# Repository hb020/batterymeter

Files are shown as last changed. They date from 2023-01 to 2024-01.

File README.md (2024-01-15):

# Handheld Battery Meter on Attiny series 2 <!-- omit in toc -->

This repository is about a "pen size" (handheld) tool for quick measurement of various types of battery resistances/impedances.

This tool uses 2 different methods for measuring impedance values:

- "standard" AC 1 kHz impedance, as used by many.
- Direct Current Impedance Spectroscopy, extracting the bulk (solution) resistance and the SEI (Solid Electrolyte Interphase) resistance, allowing better insight in both battery ageing and battery safety. Normally this would require a lengthy procedure via EIS (Electrochemical Impedance Spectroscopy) and model fitting. This tool allows to do it fast and easy.

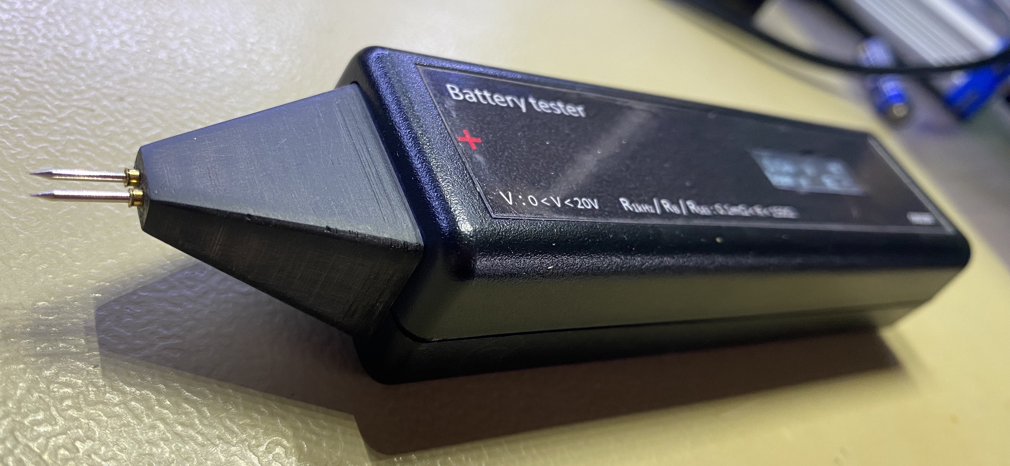
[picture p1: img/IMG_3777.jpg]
front image

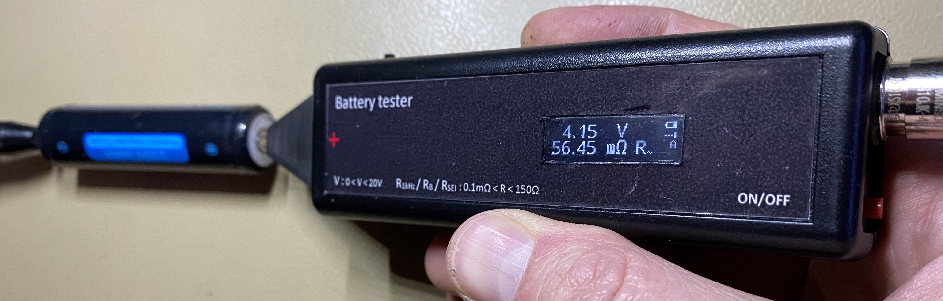
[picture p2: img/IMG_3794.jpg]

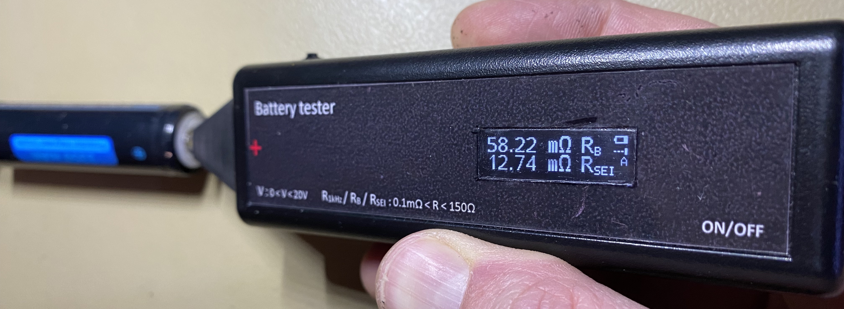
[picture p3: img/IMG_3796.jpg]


## Contents <!-- omit in toc -->

This document handles the reasoning behind the creation of this tool, the methods used, the software and the hardware.

- [Design restrictions](#design-restrictions)
- [Norms and introduction to measurement techniques used](#norms-and-introduction-to-measurement-techniques-used)
- [Battery Equivalent Circuit Model, Spectrum, and the EIS method](#battery-equivalent-circuit-model-spectrum-and-the-eis-method)
  - [Battery Equivalent Circuit Model](#battery-equivalent-circuit-model)
  - [EIS](#eis)
  - [Tools](#tools)
  - [CN0510](#cn0510)
  - [Model fitting](#model-fitting)
  - [Further information](#further-information)
- [Time Domain / DCIS method](#time-domain--dcis-method)
  - [Non-linear behaviour](#non-linear-behaviour)
  - [Pulse timing](#pulse-timing)
  - [Adaptation to other battery layouts or chemistries](#adaptation-to-other-battery-layouts-or-chemistries)
  - [Ratiometric approach](#ratiometric-approach)
  - [Offset cancelling](#offset-cancelling)
  - [Power line Frequency compensation](#power-line-frequency-compensation)
- [Internal Impedance (AC) measurement](#internal-impedance-ac-measurement)
  - [Current levels and test duration](#current-levels-and-test-duration)
  - [Implementation of the sine wave generation](#implementation-of-the-sine-wave-generation)
  - [AC Analysis method](#ac-analysis-method)
  - [ADC sampling considerations](#adc-sampling-considerations)
  - [Ratiometric approach, Offset cancelling, Power line Frequency compensation](#ratiometric-approach-offset-cancelling-power-line-frequency-compensation)
- [Internal Resistance (DC/IR) measurement](#internal-resistance-dcir-measurement)
- [CPU and Software environment](#cpu-and-software-environment)
- [Construction, Connectors, other hardware](#construction-connectors-other-hardware)
  - [Charging](#charging)
- [Buttons](#buttons)
- [Calibration](#calibration)
- [Remote control, SCPI](#remote-control-scpi)
- [Specifications](#specifications)
  - [Voltage](#voltage)
  - [Resistance](#resistance)
- [Repository contents](#repository-contents)
- [Imperfections, TODO's](#imperfections-todos)

---

## Design restrictions

This tool was designed with the following design restrictions:

- handheld, therefore:
  - small
  - limited controls, ideally by 1 finger while measuring
  - "large enough" screen
  - rechargeable
  - no need to cover a large temperature range
- fast measurement
- easy to use
- for use on regular small batteries. No large capacity car batteries or large UPS batteries, and nothing requiring extreme precision. Therefore:
  - at least 0 to 20 Ω, with, and at least 1 mΩ resolution at the lowest range.
  - at least 1V to 16V, and at least 10mV resolution.
  - at least 3 significant digits.
- precision is more important than accuracy. However, 1% accuracy should be attainable on resistance values. Voltage accuracy is of lower priority, as my DMMs can be used for that, and the voltage is less significant in most cases. Therefore:
  - aim for low noise
  - the accuracy of the measuring techniques should depend on as few as possible variables.
  - calibration must be possible.
- USB charging and USB interface
- hand assembly and hand soldering. For me, that means:
  - no BGA or QFN, as I don't have a reflow oven and am too much of a cheapskate to order stencils for the 1 or 2 PCBs I'll make.
  - 0805 components and VSSOP/MSOP 0.5mm pitch are the low limits
  - as a side effect, I can now freely use both sides of the PCB because I don't have to care about warping or components falling off the other side while soldering with hot air.
- using components that I can find in this period of component shortage. This means that sometimes there might be cheaper or better components, they were just not available when I selected them.
- using an Attiny series 2 CPU, because I wanted to try that out and it looked just capable enough. I really would have liked to use the RP2040, but it is not hand solderable enough. Maybe later.
- capable of using the probes that come with the YR1035+, as I also have that tool, and like the connector/probe ease of use/availability. It will also allow me to have easier comparisons.

## Norms and introduction to measurement techniques used

Battery impedance is a complicated subject. A battery does not have <u>one</u> impedance, and even if you get a number, it can mean many things. Also, the battery impedance depends on a lot of different things, like state of charge (SoC), state of health (SoH), temperature, and of course the measurement method. Therefore, various norms exist for measuring the various resistances and impedances of the different battery types. Some of them are:

- IEC 61951-1: NiCd
- IEC 61951-2: NiMH
- IEC 62660-1/2: Li-Ion
- IEC 61960-4: Lithium coin cells

Outside of these norms, various other test methods have arisen lately. Below is an explanation of the different methods I investigated.

---

## Battery Equivalent Circuit Model, Spectrum, and the EIS method

### Battery Equivalent Circuit Model

Various models of battery impedance exist, depending on the chemistry. For Li-Ion cells, the "Combined Randle and Warburg Circuit Model" is often cited as fairly complete, and, with some variations, also applicable to some other chemistries.

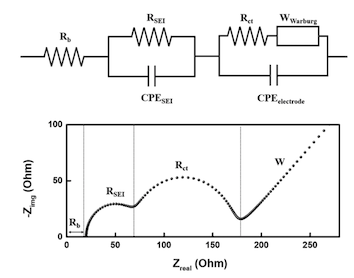
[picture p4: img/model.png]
Model and spectrum model and spectrum


*Equivalent circuit model of a Li-Ion battery half-cell system, and nyquist plot of a frequency sweep.*
([source](https://www.jecst.org/upload/pdf/jecst-2019-00528.pdf))

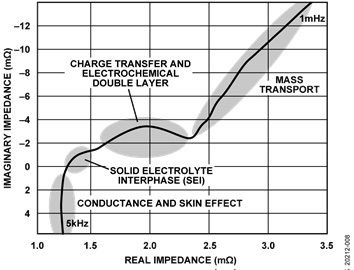
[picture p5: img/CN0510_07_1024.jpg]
Nyquist plot


*Nyquist plot, related to Li-Ion cell chemical processes.*
([source](https://www.analog.com/en/design-center/reference-designs/circuits-from-the-lab/CN0510.html))

### EIS

The EIS (Electrochemical Impedance Spectroscopy) method allows one to get a good view of the various components of the battery impedance. With this method an AC load of varying frequency is imposed on the battery, and the voltage swing over the battery is measured. The frequency sweep can go from the millihertz into the megahertz range, and can be used to generate a Nyquist plot like shown above.

Through model fitting, the values of the individual components in the model can than be determined.

For Li-Ion, the values of these components can be used as indicators.

- R<sub>b</sub> (aka R<sub>s</sub> or R<sub>Ω</sub> in other literature) = Bulk (or Solution) resistance. Increases when the battery ages.
- R<sub>SEI</sub> = Solid Electrolyte Interphase resistance. Is an indication of battery safety: it increases for example when the battery has been overcharged.
- R<sub>ct</sub> = Charge Transfer resistance. Increases when the battery is discharged, and when the temperature is lower. At a stable temperature and SoC, it is also a very good indication of battery health.

As an example, experimental results on Li-Ion batteries show that when the battery capacity drops from 3100 mAh to 2600 mAh due to ageing, the value of R<sub>b</sub> rises from 44 mΩ to 51 mΩ, the value of R<sub>SEI</sub> remains between 6 mΩ and 7 mΩ, and the value of R<sub>ct</sub> rises from 6 mΩ to 20 mΩ.

In spite of the insights EIS can give, it has a couple of drawbacks:

- The values are strongly dependent on the battery chemistry and construction details.
- Interpretation can be complicated.
- The data is too complex to show on a small screen.
- A full EIS test generally takes significant time

As a result, this method is very interesting, but unsuited for implementation in a handheld tool.

Fast measurement of full impedance spectra is possible via the use of multi-sine methods, or via time domain methods. More about this later on.

### Tools

Few "small lab" tools exist that support EIS. Examples are the [Biologic Potentiostat](https://www.biologic.net/product_category/potentiostats-galvanostats/), [Hioki IM3590 and BT4560](https://www.hioki.com/download/37483), or the [BK Precision BA8100](https://www.bkprecision.com/products/electrical-battery-testers/BA8100), all costing several thousands of Euros. But one can already get an idea about EIS via the CN0510 circuit, for a significantly lower budget:

### CN0510

An implementation example of a tool is [CN0510 from analog.com](https://www.analog.com/en/design-center/reference-designs/circuits-from-the-lab/CN0510.html). It allows EIS measurements on various types of batteries. Note however that the signal handling board (EVAL-AD5941BATZ), by default, is only usable in the frequency range of about 4Hz - 5Khz. Outside of that, the accuracy is degraded, and below 1Hz, the noise of the input circuitry gets quite noticeable (1/f noise). With the following minor modifications, 0.5Hz - 5kHz can be made possible though:

- add U4 (otherwise the first couple of seconds of measurements are totally off)
- change C5, C6, C36, C37, C38, C39 from 2.2uF to 10uF.
- change R18, R19, R2, R3, R4, R5 from 2Meg to 10Meg.

### Model fitting

For the impedance analysis and the model fitting, several software packages exist, like [ZView](https://www.scribner.com/software/) or [impedance.py](https://github.com/ECSHackWeek/impedance.py). See the [/EISMeasurements](/EISMeasurements) directory in this repository for some fitting tests with both of these tools.

### Further information

For more information on EIS and alternative methods, see for example <https://www.gamry.com/application-notes/EIS/basics-of-electrochemical-impedance-spectroscopy/> or <https://doi.org/10.1016/j.jpowsour.2020.228742>.

Note that EIS is used in a lot of fields, not only for batteries. However, research on batteries has gotten a significant boost lately with the widespread arrival of electric cars.

---

## Time Domain / DCIS method

As mentioned above, EIS frequency domain analysis is not only complicated, but also lengthy. Time domain analysis methods have come up lately that allow acceptable approximations to the results that can be obtained via EIS. One of the approaches is called DCIS (Direct Current Impedance Spectroscopy), which is described here: <https://www.mdpi.com/1996-1073/14/15/4396/htm>

The idea behind DCIS (and other time domain methods) is that when one exposes the battery to current pulses, the voltage relaxation times give away details of the different RC components in the battery model. Care must be taken to exclude non linear behaviour and to tune the current pulses in such a way that the correct components can be derived easily.

### Non-linear behaviour

One key phrase:

> In the battery model, when the polarization potential change |∆ϕ| caused by an external signal is less than 10 mV and the signal time is short enough, the effect of concentration polarization (Zd in battery model) can be ignored.

I therefore need to keep the test currents low, and the pulses short. Both requirements perfectly fit my tool's design requirements.

### Pulse timing

In regular Li-Ion batteries, the various components show at various frequencies:

- R<sub>b</sub>: > 1kHz
- R<sub>SEI</sub> (and CPE<sub>SEI</sub>): > 1Hz, < 1kHz
- R<sub>ct</sub> (and CPE<sub>electrode</sub> and W): < 1Hz

The approach is that for every individual component, 1 specific timed constant current pulse will be used. The width of the pulse is about 5 * RC time of the component. That gives:

- for R<sub>b</sub>: T<sub>1</sub> = 0.25ms
- for R<sub>SEI</sub>: T<sub>2</sub> = 10ms
- for R<sub>ct</sub>: T<sub>3</sub> = 400ms

The pulses are spaced out by a small relaxation time. The voltage drop over the battery is measured at the end of each current pulse, and the battery resistance at that point in time is calculated:

- for T<sub>1</sub>: V<sub>drop</sub> / I<sub>pulse</sub> = R<sub>b</sub>
- for T<sub>2</sub>: V<sub>drop</sub> / I<sub>pulse</sub> = R<sub>b</sub> + R<sub>SEI</sub>
- for T<sub>3</sub>: V<sub>drop</sub> / I<sub>pulse</sub> = R<sub>b</sub> + R<sub>SEI</sub> + R<sub>ct</sub>

Unfortunately, I will want to do multiple measurements to drown out noise and do power line frequency compensation. That makes T<sub>3</sub> unsuited for my tool, and I must limit myself to  R<sub>b</sub> and R<sub>SEI</sub>.

### Adaptation to other battery layouts or chemistries

The timings mentioned above are suitable for your average Li-Ion 18650 cell. If you want to use the DCIS method on other battery layouts or chemistries, you can adapt the timings via SCPI commands (see `CAL:T(1|2|PAUSE) {uint16}` below).

### Ratiometric approach

The current pulse is sent through the battery, that is placed in series with a known resistor.
The battery resistance is deducted from the relation between the voltage fluctuation over the known resistor and the voltage fluctuation over the battery. Hence, there is no need for a known current source, nor a known voltage reference.

With U<sub>batt</sub> as the voltage drop over the battery, U<sub>ref</sub> the voltage over the reference resistor, and R<sub>ref</sub> the reference resistor: R<sub>batt</sub> = R<sub>ref</sub> * (U<sub>batt</sub>/U<sub>ref</sub>).

Since U<sub>batt</sub> and U<sub>ref</sub> are so small, they are amplified by an AC coupled low noise instrumentation amplifier. The output signal is fed into the differential ADC of the processor. In order to avoid amplification differences and other signal path differences, multiplexing via a common measurement circuit is used. An input switch allows switching between the battery and the reference resistor.

The frequency cut-off point of the high-pass filter at the input of the instrumentation amplifier is well below the frequencies used in the measurements.

### Offset cancelling

The (potentially large) DC offset at the entry of the circuit is cancelled at the start of the measurements, by a low impedance short of the signal to VCC/2. The short is applied for as long is needed, and stopped when the processor sees a close to 0V differential signal on the ADC.

### Power line Frequency compensation

In order to reduce the noise and the influence of the power line frequency, multiple samples are taken, and the results are averaged. The timing of the samples is adapted to the configured power line frequency: an identical number of samples is taken for each opposing polarity of the power line signal.

The software allows setting of the power line frequency (50 or 60) via SCPI commands.

---

## Internal Impedance (AC) measurement

This is the industry standard AC 1kHz test. A small 1kHz current (ideally sine wave) is applied to the battery, and the AC voltage at the battery is measured. The impedance is then deducted from the current and the voltage.
This method is widespread, low power, and fast, so I can include it in my tool.

### Current levels and test duration

The maximum voltage swing allowed depends on the battery type, as above certain levels, the values would be skewed by other factors. For NiCd, that limit is about 20mV, and for Lithium chemistries, 10mV seems to be indicated. As a result, I do not set a test specific current, but adapt the test current to the selected range.

The "correct" duration of the test varies. EC 61951-1 for example states that the test duration must be 1 to 5 seconds, but that is not handy for fast manual use. A test duration of 100ms suffices normally.

### Implementation of the sine wave generation

The CPU I chose does not have a sine wave generator. It does have PWM, but making a sine wave with that was hard to do while running the ADC. As a result, I generate a 1kHz square wave on CPU, and do the transformation to a sine wave with an analog phase-shift circuit. That signal is then, after some amplification and level shifting, fed into a voltage controlled current sink.

### AC Analysis method

Instead of a full fledged FFT/DFT, Goertzel's Algorithm is used. It is essentially a mathematical bandpass filter that gives a magnitude (and phase) reading. It is especially suited as I generate the 1kHz tone myself and can sync the ADC sampling to that tone generation. As a result, it is very light on resources: I can do the calculations while sampling, and do not need large memory buffers.

About the configuration of Goertzel:

- nr_of_samples (N) should be as high as possible:
  - sample_rate/N is bin width.
  - more samples therefore gives more noise suppression
- Target frequencies must be integer multiples of sample_rate/N

Some of the inspirations:

- <https://www.embedded.com/the-goertzel-algorithm/>
- <https://fr.mathworks.com/matlabcentral/answers/?language=fr%2Cen&search_origin=ans_browse&term=goertzel>

### ADC sampling considerations

The CPU having limited RAM, I prefer to do the tone generation, ADC sampling and AC analysis all in sync, run-time. I do not sample and analyse later, as that would take too much RAM. It also gives me the possibility to make the sampling as long as I want, increasing noise suppression. It however requires an optimised ADC loop, so I go outside of megaTinyCore's analogRead() function.

As I have low noise pre-amps, I do not use the PGA: I set gain 0.

The trigger generator is TCA0, the most capable of the timers on the CPU, and I trigger the ADC sampling via the Event system (ADC_START_EVENT_TRIGGER_gc and USERADC0START). During sampling, I generate the 1kHz square wave in code, and do the Goertzel calculations.
Tests have shown that at a 10kHz trigger signal, I have about 20us CPU time left per sample. 12kHz would not be possible, unless I raise the ADC clock rate. Maybe also CCL could help, but I haven't looked.

Interrupts are only used for error conditions on the ADC. Other interrupt sources, like the time library, are disabled, as it would provoke jitter or overruns.

As this is time critical code, debugging support is available in code, via USEREVSYSEVOUTC for example.

I do not use tone(), as that is interrupt driven.

### Ratiometric approach, Offset cancelling, Power line Frequency compensation

A sine wave of 1 kHz is sent through the battery, that is placed in series with a known resistor.
The battery resistance is deducted from the relation between the AC voltage over the known resistor and the AC voltage over the battery. Hence, there is no need for a known current source, nor a known voltage reference.

For more details, see the chapter on "Ratiometric approach" in the description of the DCIS method.

Also here, DC offset cancelling and power line frequency compensation is used. See the related chapters in the description of the DCIS method.

---

## Internal Resistance (DC/IR) measurement

This method is frequently encountered, because it is very simple. It is in essence a DC measurement technique.

> The cell shall be discharged at a constant current of value I<sub>1</sub>. At the end of a discharge period of T<sub>1</sub> s, the voltage U<sub>1</sub> during discharge shall be measured and recorded. The discharge current shall then be immediately increased to a constant value of I<sub>2</sub>, and the corresponding voltage U<sub>2</sub> during discharge shall be measured and recorded again at the end of a discharge period of T<sub>2</sub> s.

Therefore: R<sub>dc</sub> = (U<sub>1</sub> - U<sub>2</sub>)/(I<sub>2</sub> - I<sub>1</sub>)

The currents I<sub>1</sub> and I<sub>2</sub>, and the times T<sub>1</sub> and T<sub>2</sub> depend on the type and capacity of the battery. Example: For NiCd, I<sub>1</sub> is normally between 0.2 and 1 times the C value in Amps, I<sub>2</sub> = 10 * I<sub>1</sub>, T<sub>1</sub> = 10, T<sub>2</sub> = 3. For Lead Acid batteries, the currents can become even larger.

Those large currents, and the accompanying dissipation, make it unsuited for integration in a small handheld tool. Also, because this is such a crude method, abstracting most of the battery model, I am not using this method.

---

## CPU and Software environment

- Arduino IDE (unfortunately. platformIO was not very mature at the time of creation: board support had just arrived.)
- megaTinyCore
- CPU: Attiny 3266-SU (SOIC300, non automotive, 32kB Flash, 3kB RAM, 256B EEPROM)
- Display (SSD1306) via Tiny4kOLED (not SSD1306_minimal, as that is less maintained)
- SparkFun_PCA9536_Arduino_Library
- a modified and local version of vrekrer's scpi_parser

Please note that the flash memory is close to the limit: it is 97% full.

## Construction, Connectors, other hardware

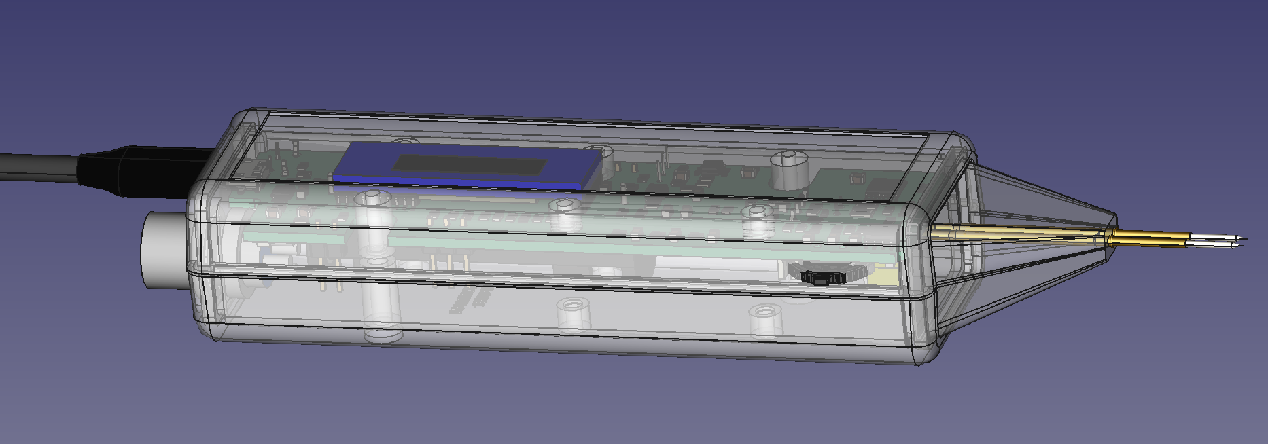
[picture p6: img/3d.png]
3d image

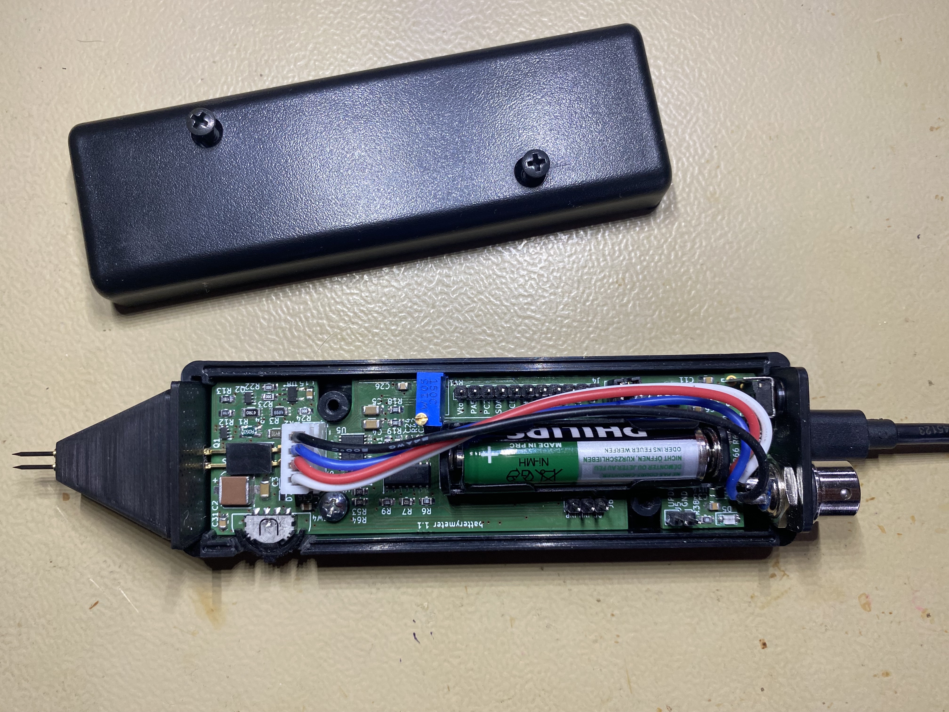
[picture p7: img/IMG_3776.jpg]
open image


The case chosen is a Hammond 1593DBK. That case comes with flat and curved front/back panels. Use the flat one for the back.

The nose cone is 3D printed, see the [nose cone STEP file](/freecad/noseCone.STEP). The holes for the pins may be too small, I had to drill them out.

The pogo pins in the nose cone are regular R100-1W sockets, with P100-B1 pogo pins. For images and dimensions, see the `pogo-*` files in the [/img](/img) folder.

The probe connector at the back is a "avionics" XS10 4P male connector, the same as on the YR1035+. This connector accepts regular YR1035+ compatible 4W probes, or in conjunction with the nose pogo pins, a custom made - probe (just half of the regular 4W probe). The nose pogo pins are directly connected to the + pins on the XS10 connector. As a result, one can also connect a 4W rig:

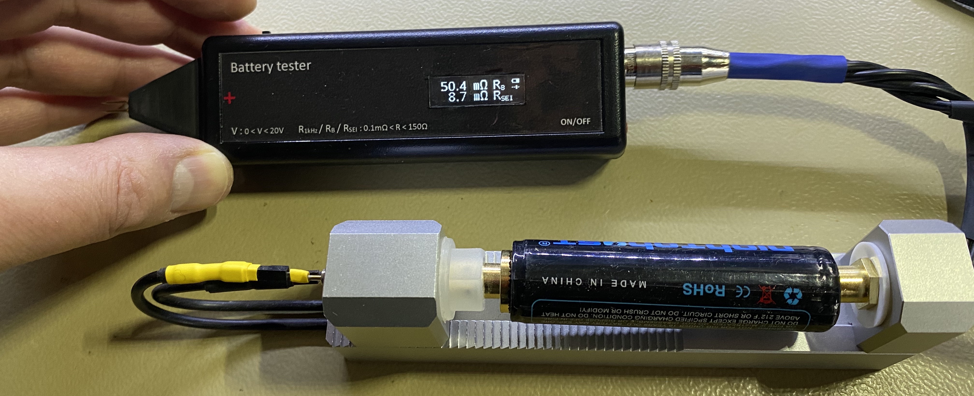
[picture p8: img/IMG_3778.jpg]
rig image


The serial connector/charge plug is a USB micro B. I should have chosen USB-C, but I still had a lot of USB micro B connectors.

The navigation switch is a SLLB510100 from Alps Alpine. You probably need some glue to fix it on the PCB, as the "fixing" tabs on the side are very/too small.

The reference resistors are all used in a 4W (kelvin) setup, either through the use of 4W resistors, or in a "poor man's" way, via the PCB layout:

kelvin connection.

All components on the board are specified in the kicad files. The choice of components is, as can be expected, influenced by the component shortage during 2021-2022.

The input circuitry is protected against reverse polarity and moderate overvoltage.

### Charging

If a rechargeable battery is used, the USB charges the battery via trickle charging at about 0.05C for your average 850mAh NiMh AAA battery. This charge current is so little that charging while ON is not possible. Therefore: Charge while OFF.

## Buttons

ON: short press button at the back.

OFF: long press button at the back, or via software control.

Switch between AC and DCIS measurement, or leave remote control: press the navigation switch.

Change range: via left/right of the navigation switch. The 'Auto' range is at both ends.

Note that due to the time-critical way the measurements are done, button presses are only detected between measurements, sometimes resulting in sluggish reactivity. See below under [Imperfections](#imperfections-todos).

## Calibration

The procedure for the calibration of the trim pot on the PCB is explained in the schematic.

The calibration of the current ranges is best done through measurement of the used resistors, and storage via the SCPI commands, or via code.

## Remote control, SCPI

By default, the meter prints out all measurement results on the USB serial output:

- __AC__: "AC: {R<sub>~</sub>}, {test voltage} V"
- __DCIS__: "DCIS: {R<sub>b</sub>}, {R<sub>SEI</sub>}, {test voltage} V"

The serial interface also supports a reduced set of SCPI commands. Any command (valid or not valid) on the serial interface will interrupt "local" measurements, and will allow remote control via the SCPI commands. To go back to "local" control, just press the navigation switch.

SCPI commands should be terminated with newline. Chaining (;) is not supported.

The following SCPI commands are supported:

- `*IDN?`: Identify.
- `*HELP?`: Usage. List all supported commands.
- `SYST:ERR?`: Show the last error message.
- `SYST:DIAG:(ON|OFF)`: activate or deactivate diagnostic output. Once set, it prints additional info after a measurement, even when going back to "local" control.
- `MEAS:VOLT:(INP|INT|AC|DCIS)?`: various measurements, one per command.
  - `INP`: input (test) voltage
  - `INT`: internal battery voltage and battery gauge percentage
  - `AC`: 1kHz impedance: R<sub>~</sub>
  - `DCIS`: R<sub>B</sub> and R<sub>SEI</sub>
- `CONF:RANGE (AUTO|1|2|3|4)`: Set the current range.
- `CONF:RANGE?`: Get the current range.
- Calibration commands:
  - `CAL:INPV {uint16}`: Set input voltage multiplication factor (mV@1V).
  - `CAL:INPO {int16}`: Set input ADC offset (between +500 and -500). Best is to define INPV and INPO via fitting, to compensate for some small non-linearities.
  - `CAL:INTV {uint16}`: Set internal voltage multiplication factor (mV@1V).
  - `CAL:VMIN {uint16}`: Set internal battery range min (mV).
  - `CAL:VMAX {uint16}`: Set internal battery range max (mV).
  - `CAL:R(1|2|3|4) {uint16}`: Set reference resistor value, for a specific range. The integer value to be entered is to be expressed as a multiple of a factor that depends on the range: 1:mΩ, 2:100µΩ, 3: 10µΩ, 4:µΩ.
  - `CAL:T(1|2|PAUSE) {uint16}`:  Set DCIS timings for T<sub>1</sub>, T<sub>2</sub>, and T<sub>pause</sub> (the pause time between the pulses), in (µs). T<sub>1</sub> must be between 100 and 500,  T<sub>2</sub> between 100 and 50000, and T<sub>pause</sub> between 5000 and 10000.
  - `CAL:PLF (50|60)`: Set power line Frequency (50 or 60).
  - `CAL:SAVE`: Save all cal values to EEPROM.
  - `DIAG:CAL?`: Show all active calibration values (may not be saved yet).

---

## Specifications

### Voltage

| Type of voltage | Range | Resolution |
| :--- | ---: | ---: |
| Input/Test | 0 - 20.00 V | 10 mV |
| Internal battery | 0.800 - 2.000 V | 1 mV |

Below 1.1V input voltage, the resistance measurements will not work, and the display will show "low v".

Internal battery voltage is only readable via SCPI. Below 0.8V internal battery voltage, the device will likely not function.

### Resistance

The numbers below apply to all resistance types: (R<sub>~</sub>, R<sub>b</sub>, R<sub>SEI</sub>):

| Range | range | resolution | max test current |
| :--- | ---: | ---: | ---: |
| 1 | 150.00 Ω | 10 mΩ | 0.1 mA |
| 2 | 10.000 Ω | 1 mΩ | 1 mA |
| 3 | 1000.0 mΩ | 0.1 mΩ | 10 mA |
| 4 | 100.00 mΩ | 0.01 mΩ | 100 mA |

Accuracy depends on the calibration, but with proper calibration, can be as good as 0.05% full scale.

The software (`settingsShow4Digits()`) allows the removal of the least significant digit.

---

## Repository contents

- [/batterymeter](/batterymeter/): Arduino source code.
- [/case](/case/): some help files for the front panel.
- [/doc](/doc/): various documentation.
- [/EISMeasurements](/EISMeasurements/): examples of model fitting.
- [/freecad](/freecad/): 3D model of the PCB, case and nose cone.
- [/img](/img/): Some images used in this file, plus some other images.
- [/kicad](/kicad/): Schemas and PCBs. For those that do not have kicad, PDF images of the schemas and boards are also provided.
  - [batterymeter](/kicad/batterymeter/): the subject of this repository.
  - [impedance_testboard](/kicad/impedance_testboard/): a test board I used to create a low impedance, repeatable, test subject. This board allowed me to test any impedance above 2,2mΩ@1kHz, up to 16V DC.
  - [YR1035Plus](/kicad/YR1035Plus/): input circuit of the YR1035+, for reference.
- [/ltspice](/ltspice/): various ad hoc simulations, with spice models of the various components I investigated.

---

## Imperfections, TODO's

- __Current waveform and polarity__: In order to keep power requirements low, all current measurements are done via a current sink, as opposed to a alternating source/sink. This results in a DC component on the current waveform. It also requires a fixed polarity: connecting the battery backwards will not damage the tool, but measurement will not be possible. For the intended use case (handheld, short measurements, low current), this has little influence. If I were to expand this tool to higher currents, full 2 or 4 quadrant use would be better.
- __Precision__: the ADC used is only 12 bits, and for the DCIS measurements I even only use single signed signals on the differential input of the ADC. As a result, do not expect more than 3 or 3.5 digits out of the tool, especially in DCIS mode.  
- __Auto range and DCIS measurements__: In some cases, the batteries react in a non linear way to the DCIS current pulses. When the meter is set to auto ranging, this can result in continuous switching between ranges. I need to investigate this more, as this can be solved via software.
- __Sluggish UI__: Due to the time-critical way the measurements are done, button presses are only detected between measurements, sometimes resulting in sluggish reactivity. I need to investigate this more, as this can be solved via software.
- __Some chargers lock up the device while connected__: With some chargers, when you try to power on the device, while connected to the charger, the device seems locked up, and will not turn on. Or it will turn on and will not react to the navigation button. In that case, either disconnect the charger, or use long press on the power button to force a hard power off. After that, the device will resume to work correctly. The cause lies in the fact that some chargers try to negotiate the charging power envelope, by sending signals over the USB data lines. This results in the serial chip leaking stray voltages into the 3V3 line, locking up some of the chips on the board. Preventing this would require a hardware change.
- __Battery life__: in the off state, the device draws about 1.8uA. While on, the current draw is about 45mA. Although these numbers are perfectly acceptable, they might be improved. Also, with a bigger case, AA batteries or double AAA batteries would be possible.
- __ADC overload during AC sampling__: ADC input signal overloads can unfortunately not be detected during the AC sampling loop (not enough cpu time left), so I must do a short validating pre-run before the real sampling. I might use comparators for overload detection, but I haven't investigated.
- __Flash nearly full__: There is not much space left for modifications. Skimp on the SCPI help texts or even commands? Remove unused characters in the fonts? Other CPU?
- __Bigger screen__: I would have liked a bigger screen.

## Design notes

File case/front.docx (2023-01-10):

Battery tester

+

V : 0 < V < 20V R1kHz / RB / RSEI : 0.1mΩ < R < 150Ω ON/OFF

Spacer 19.5mm

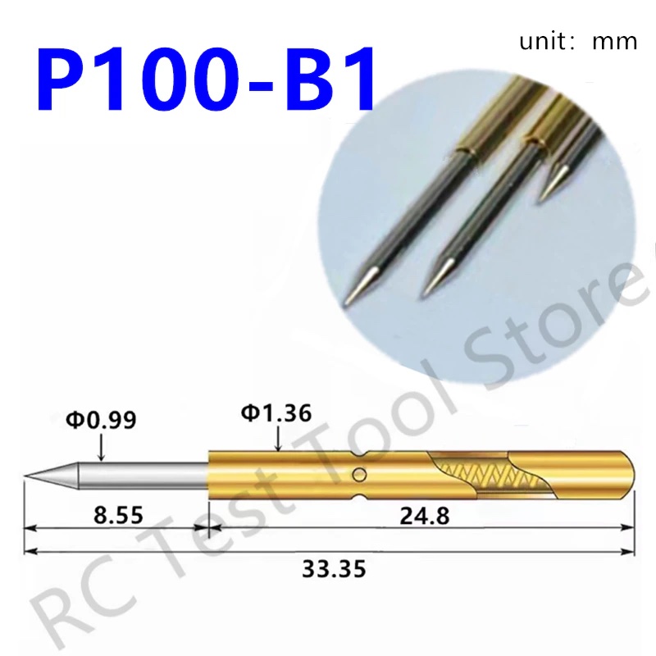
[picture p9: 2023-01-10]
img/pogo-P100.jpg

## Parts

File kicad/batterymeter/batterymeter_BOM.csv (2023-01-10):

Source: | /Users/hboot/Documents/personal/bricolage/HomeProjects/batterymeter/kicad/batterymeter/batterymeter.kicad_sch
Date: | 2023 January 08, Sunday 09:40:47
Tool: | Eeschema (6.0.10-0)
Generator: | /Applications/KiCad/KiCad.app/Contents/SharedSupport/plugins/bom_csv_grouped_by_value.py
Component Count: | 143
Individual Components:
Item | Qty | Reference(s) | Value | LibPart | Footprint | Datasheet
 |  | BT1 | Battery_Cell | Device:Battery_Cell | Battery:BatteryHolder_Keystone_2466_1xAAA | ~
 |  | C1 | 100nF | Device:C | Capacitor_SMD:C_0805_2012Metric_Pad1.18x1.45mm_HandSolder | ~
 |  | C2 | 100uF 25V | Device:C | mylib:KCM55WC71E107MH13 | ~
 |  | C3 | 100uF 6.3V | Device:C | Capacitor_SMD:C_1206_3216Metric_Pad1.33x1.80mm_HandSolder | ~
 |  | C4 | 100uF 6.3V | Device:C | Capacitor_SMD:C_1206_3216Metric_Pad1.33x1.80mm_HandSolder | ~
 |  | C5 | 100uF 6.3V | Device:C | Capacitor_SMD:C_1206_3216Metric_Pad1.33x1.80mm_HandSolder | ~
 |  | C6 | 10uF | Device:C | Capacitor_SMD:C_0805_2012Metric_Pad1.18x1.45mm_HandSolder | ~
 |  | C7 | 10uF | Device:C | Capacitor_SMD:C_0805_2012Metric_Pad1.18x1.45mm_HandSolder | ~
 |  | C8 | 100nF | Device:C | Capacitor_SMD:C_0805_2012Metric_Pad1.18x1.45mm_HandSolder | ~
 |  | C9 | 10uF | Device:C | Capacitor_SMD:C_0805_2012Metric_Pad1.18x1.45mm_HandSolder | ~
 |  | C10 | 100nF | Device:C | Capacitor_SMD:C_0805_2012Metric_Pad1.18x1.45mm_HandSolder | ~
 |  | C11 | 10uF | Device:C | Capacitor_SMD:C_0805_2012Metric_Pad1.18x1.45mm_HandSolder | ~
 |  | C12 | 100nF | Device:C | Capacitor_SMD:C_0805_2012Metric_Pad1.18x1.45mm_HandSolder | ~
 |  | C13 | 100pF | Device:C | Capacitor_SMD:C_0805_2012Metric_Pad1.18x1.45mm_HandSolder | ~
 |  | C14 | 100nF | Device:C | Capacitor_SMD:C_0805_2012Metric_Pad1.18x1.45mm_HandSolder | ~
 |  | C15 | 100nF | Device:C | Capacitor_SMD:C_0805_2012Metric_Pad1.18x1.45mm_HandSolder | ~
 |  | C16 | 10nF | Device:C | Capacitor_SMD:C_0805_2012Metric_Pad1.18x1.45mm_HandSolder | ~
 |  | C17 | 10nF | Device:C | Capacitor_SMD:C_0805_2012Metric_Pad1.18x1.45mm_HandSolder | ~
 |  | C18 | 10nF | Device:C | Capacitor_SMD:C_0805_2012Metric_Pad1.18x1.45mm_HandSolder | ~
 |  | C19 | 10nF | Device:C | Capacitor_SMD:C_0805_2012Metric_Pad1.18x1.45mm_HandSolder | ~
 |  | C20 | 1uF | Device:C | Capacitor_SMD:C_0805_2012Metric_Pad1.18x1.45mm_HandSolder | ~
 |  | C21 | 100nF | Device:C | Capacitor_SMD:C_0805_2012Metric_Pad1.18x1.45mm_HandSolder | ~
 |  | C22 | 100nF | Device:C | Capacitor_SMD:C_0805_2012Metric_Pad1.18x1.45mm_HandSolder | ~
 |  | C23 | 100nF | Device:C | Capacitor_SMD:C_0805_2012Metric_Pad1.18x1.45mm_HandSolder | ~
 |  | C24 | 1uF | Device:C | Capacitor_SMD:C_0805_2012Metric_Pad1.18x1.45mm_HandSolder | ~
 |  | C25 | 10uF | Device:C | Capacitor_SMD:C_0805_2012Metric_Pad1.18x1.45mm_HandSolder | ~
 |  | C26 | 100nF | Device:C | Capacitor_SMD:C_0805_2012Metric_Pad1.18x1.45mm_HandSolder | ~
 |  | C27 | 33pF | Device:C | Capacitor_SMD:C_0805_2012Metric_Pad1.18x1.45mm_HandSolder | ~
 |  | C28 | 10nF | Device:C | Capacitor_SMD:C_0805_2012Metric_Pad1.18x1.45mm_HandSolder | ~
 |  | C29 | 10nF | Device:C | Capacitor_SMD:C_0805_2012Metric_Pad1.18x1.45mm_HandSolder | ~
 |  | C30 | 10nF | Device:C | Capacitor_SMD:C_0805_2012Metric_Pad1.18x1.45mm_HandSolder | ~
 |  | C31 | 100nF | Device:C | Capacitor_SMD:C_0805_2012Metric_Pad1.18x1.45mm_HandSolder | ~
 |  | C32 | 10uF | Device:C | Capacitor_SMD:C_0805_2012Metric_Pad1.18x1.45mm_HandSolder | ~
 |  | C33 | 100nF | Device:C | Capacitor_SMD:C_0805_2012Metric_Pad1.18x1.45mm_HandSolder | ~
 |  | C34 | 100nF | Device:C | Capacitor_SMD:C_0805_2012Metric_Pad1.18x1.45mm_HandSolder | ~
 |  | C35 | 10uF | Device:C | Capacitor_SMD:C_0805_2012Metric_Pad1.18x1.45mm_HandSolder | ~
 |  | D1 | MMBZ20VAL,215 | Diode:MMBZxx | Package_TO_SOT_SMD:SOT-23 | http://www.onsemi.com/pub/Collateral/MMBZ5V6ALT1-D.PDF
 |  | D2 | VESD03C1-02V | Device:D_Zener | Diode_SMD:D_SOD-523 | ~
 |  | D4 | 1N4148 | Diode:1N4148 | Diode_SMD:D_SOD-123 | https://assets.nexperia.com/documents/data-sheet/1N4148_1N4448.pdf
 |  | D5 | LED | Device:LED | LED_SMD:LED_1206_3216Metric_Pad1.42x1.75mm_HandSolder | ~
 |  | D6 | VESD03C1-02V | Device:D_Zener | Diode_SMD:D_SOD-523 | ~
 |  | D7 | VESD03C1-02V | Device:D_Zener | Diode_SMD:D_SOD-523 | ~
 |  | F1 | PTC 100mA | Device:Polyfuse | Fuse:Fuse_1206_3216Metric_Pad1.42x1.75mm_HandSolder | ~
 |  | F2 | PTC 100mA | Device:Polyfuse | Fuse:Fuse_1206_3216Metric_Pad1.42x1.75mm_HandSolder | ~
 |  | F3 | PTC 100mA | Device:Polyfuse | Fuse:Fuse_1206_3216Metric_Pad1.42x1.75mm_HandSolder | ~
 |  | F4 | Polyfuse | Device:Polyfuse | Fuse:Fuse_1206_3216Metric_Pad1.42x1.75mm_HandSolder | ~
 |  | J1 | Conn_01x02_Female | Connector:Conn_01x02_Female | Connector_PinSocket_2.54mm:PinSocket_1x02_P2.54mm_Horizontal | ~
 |  | J2 | Conn_01x04_Male | Connector:Conn_01x04_Male | Connector_JST:JST_XH_B4B-XH-A_1x04_P2.50mm_Vertical | ~
 |  | J3 | USB_B_Micro | Connector:USB_B_Micro | mylib:USB_Micro-B_mine | ~
 |  | J4 | Conn_01x11_Male | Connector:Conn_01x11_Male | Connector_PinHeader_2.54mm:PinHeader_1x11_P2.54mm_Vertical | ~
 |  | J5 | Conn_01x02_Male | Connector:Conn_01x02_Male | Connector_PinHeader_2.54mm:PinHeader_1x02_P2.54mm_Vertical | ~
 |  | J6 | Conn_01x03_Male | Connector:Conn_01x03_Male | Connector_PinHeader_2.54mm:PinHeader_1x03_P2.54mm_Vertical | ~
 |  | J9 | Conn_01x02_Male | Connector:Conn_01x02_Male | Connector_PinHeader_2.54mm:PinHeader_1x02_P2.54mm_Vertical | ~
 |  | JP1 | Jumper_2_Bridged | Jumper:Jumper_2_Bridged | Jumper:SolderJumper-2_P1.3mm_Bridged_Pad1.0x1.5mm | ~
 |  | L1 | 4.7uH Shld | Device:L_Ferrite | mylib:L_Coilcraft_LPS4018 | ~
 |  | Q1 | DMN62D0UDW-13 | Transistor_FET:FDG1024NZ | Package_TO_SOT_SMD:SOT-363_SC-70-6 | https://www.onsemi.com/pub/Collateral/FDG1024NZ-D.pdf
 |  | Q2 | DMN62D0UDW-13 | Transistor_FET:FDG1024NZ | Package_TO_SOT_SMD:SOT-363_SC-70-6 | https://www.onsemi.com/pub/Collateral/FDG1024NZ-D.pdf
 |  | R1 | 50mOhm precision | Device:R_Shunt | mylib:R_Shunt_Ohmite_LVK12_ALT | ~
 |  | R2 | 0.5 Ohm precision | Device:R_Shunt | mylib:R_1206_3216Metric_4Wire | ~
 |  | R3 | 5 Ohm precision | Device:R_Shunt | mylib:R_1206_3216Metric_4Wire | ~
 |  | R4 | 45 Ohm precision | Device:R_Shunt | mylib:R_1206_3216Metric_4Wire | ~
 |  | R5 | 10M | Device:R | Resistor_SMD:R_0805_2012Metric_Pad1.20x1.40mm_HandSolder | ~
 |  | R6 | 100k | Device:R | Resistor_SMD:R_0805_2012Metric_Pad1.20x1.40mm_HandSolder | ~
 |  | R7 | 1k | Device:R | Resistor_SMD:R_0805_2012Metric_Pad1.20x1.40mm_HandSolder | ~
 |  | R8 | 10M | Device:R | Resistor_SMD:R_0805_2012Metric_Pad1.20x1.40mm_HandSolder | ~
 |  | R9 | 100k | Device:R | Resistor_SMD:R_0805_2012Metric_Pad1.20x1.40mm_HandSolder | ~
 |  | R10 | 220 | Device:R | Resistor_SMD:R_0805_2012Metric_Pad1.20x1.40mm_HandSolder | ~
 |  | R11 | 10k | Device:R | Resistor_SMD:R_0805_2012Metric_Pad1.20x1.40mm_HandSolder | ~
 |  | R12 | 470 | Device:R | Resistor_SMD:R_0805_2012Metric_Pad1.20x1.40mm_HandSolder | ~
 |  | R13 | 4k7 | Device:R | Resistor_SMD:R_0805_2012Metric_Pad1.20x1.40mm_HandSolder | ~
 |  | R14 | 1M | Device:R | Resistor_SMD:R_0805_2012Metric_Pad1.20x1.40mm_HandSolder | ~
 |  | R15 | 1M | Device:R | Resistor_SMD:R_0805_2012Metric_Pad1.20x1.40mm_HandSolder | ~
 |  | R16 | 270 | Device:R | Resistor_SMD:R_0805_2012Metric_Pad1.20x1.40mm_HandSolder | ~
 |  | R17 | 270 | Device:R | Resistor_SMD:R_0805_2012Metric_Pad1.20x1.40mm_HandSolder | ~
 |  | R18 | 10M | Device:R | Resistor_SMD:R_0805_2012Metric_Pad1.20x1.40mm_HandSolder | ~
 |  | R19 | 10M | Device:R | Resistor_SMD:R_0805_2012Metric_Pad1.20x1.40mm_HandSolder | ~
 |  | R20 | 47 | Device:R | Resistor_SMD:R_0805_2012Metric_Pad1.20x1.40mm_HandSolder | ~
 |  | R21 | 47 | Device:R | Resistor_SMD:R_0805_2012Metric_Pad1.20x1.40mm_HandSolder | ~
 |  | R22 | 0 | Device:R | Resistor_SMD:R_0805_2012Metric_Pad1.20x1.40mm_HandSolder | ~
 |  | R23 | 0 | Device:R | Resistor_SMD:R_0805_2012Metric_Pad1.20x1.40mm_HandSolder | ~
 |  | R24 | 0 | Device:R | Resistor_SMD:R_0805_2012Metric_Pad1.20x1.40mm_HandSolder | ~
 |  | R25 | 47k | Device:R | Resistor_SMD:R_0805_2012Metric_Pad1.20x1.40mm_HandSolder | ~
 |  | R26 | 47k | Device:R | Resistor_SMD:R_0805_2012Metric_Pad1.20x1.40mm_HandSolder | ~
 |  | R27 | 47k | Device:R | Resistor_SMD:R_0805_2012Metric_Pad1.20x1.40mm_HandSolder | ~
 |  | R28 | 100k | Device:R | Resistor_SMD:R_0805_2012Metric_Pad1.20x1.40mm_HandSolder | ~
 |  | R29 | 100k | Device:R | Resistor_SMD:R_0805_2012Metric_Pad1.20x1.40mm_HandSolder | ~
 |  | R30 | 8k2 | Device:R | Resistor_SMD:R_0805_2012Metric_Pad1.20x1.40mm_HandSolder | ~
 |  | R31 | 100k | Device:R | Resistor_SMD:R_0805_2012Metric_Pad1.20x1.40mm_HandSolder | ~
 |  | R32 | 82k | Device:R | Resistor_SMD:R_0805_2012Metric_Pad1.20x1.40mm_HandSolder | ~
 |  | R33 | 15k | Device:R | Resistor_SMD:R_0805_2012Metric_Pad1.20x1.40mm_HandSolder | ~
 |  | R34 | 1k | Device:R | Resistor_SMD:R_0805_2012Metric_Pad1.20x1.40mm_HandSolder | ~
 |  | R35 | 1k | Device:R | Resistor_SMD:R_0805_2012Metric_Pad1.20x1.40mm_HandSolder | ~
 |  | R36 | 47k | Device:R | Resistor_SMD:R_0805_2012Metric_Pad1.20x1.40mm_HandSolder | ~
 |  | R37 | 100 | Device:R | Resistor_SMD:R_1206_3216Metric_Pad1.30x1.75mm_HandSolder | ~
 |  | R38 | 1k | Device:R | Resistor_SMD:R_0805_2012Metric_Pad1.20x1.40mm_HandSolder | ~
 |  | R39 | 1M | Device:R | Resistor_SMD:R_0805_2012Metric_Pad1.20x1.40mm_HandSolder | ~
 |  | R40 | 1k | Device:R | Resistor_SMD:R_0805_2012Metric_Pad1.20x1.40mm_HandSolder | ~
 |  | R41 | 100k | Device:R | Resistor_SMD:R_0805_2012Metric_Pad1.20x1.40mm_HandSolder | ~
 |  | R42 | 100k | Device:R | Resistor_SMD:R_0805_2012Metric_Pad1.20x1.40mm_HandSolder | ~
 |  | R43 | 9M1 1% | Device:R | Resistor_SMD:R_0805_2012Metric_Pad1.20x1.40mm_HandSolder | ~
 |  | R44 | 1M 1% | Device:R | Resistor_SMD:R_0805_2012Metric_Pad1.20x1.40mm_HandSolder | ~
 |  | R45 | 100k | Device:R | Resistor_SMD:R_0805_2012Metric_Pad1.20x1.40mm_HandSolder | ~
 |  | R46 | 10k | Device:R | Resistor_SMD:R_0805_2012Metric_Pad1.20x1.40mm_HandSolder | ~
 |  | R47 | 10k | Device:R | Resistor_SMD:R_0805_2012Metric_Pad1.20x1.40mm_HandSolder | ~
 |  | R48 | 4k7 | Device:R | Resistor_SMD:R_0805_2012Metric_Pad1.20x1.40mm_HandSolder | ~
 |  | R49 | 0 | Device:R | Resistor_SMD:R_0805_2012Metric_Pad1.20x1.40mm_HandSolder | ~
 |  | R50 | 0 | Device:R | Resistor_SMD:R_0805_2012Metric_Pad1.20x1.40mm_HandSolder | ~
 |  | R51 | 0 | Device:R | Resistor_SMD:R_0805_2012Metric_Pad1.20x1.40mm_HandSolder | ~
 |  | R52 | 0 | Device:R | Resistor_SMD:R_0805_2012Metric_Pad1.20x1.40mm_HandSolder | ~
 |  | R53 | 68 | Device:R | Resistor_SMD:R_0805_2012Metric_Pad1.20x1.40mm_HandSolder | ~
 |  | R54 | 0 | Device:R | Resistor_SMD:R_0805_2012Metric_Pad1.20x1.40mm_HandSolder | ~
 |  | R55 | 0 | Device:R | Resistor_SMD:R_0805_2012Metric_Pad1.20x1.40mm_HandSolder | ~
 |  | R56 | 0 | Device:R | Resistor_SMD:R_0805_2012Metric_Pad1.20x1.40mm_HandSolder | ~
 |  | R57 | 0 | Device:R | Resistor_SMD:R_0805_2012Metric_Pad1.20x1.40mm_HandSolder | ~
 |  | R58 | 120 | Device:R | Resistor_SMD:R_0805_2012Metric_Pad1.20x1.40mm_HandSolder | ~
 |  | R59 | 0 | Device:R | Resistor_SMD:R_0805_2012Metric_Pad1.20x1.40mm_HandSolder | ~
 |  | R60 | 100k | Device:R | Resistor_SMD:R_0805_2012Metric_Pad1.20x1.40mm_HandSolder | ~
 |  | R61 | 10k | Device:R | Resistor_SMD:R_0805_2012Metric_Pad1.20x1.40mm_HandSolder | ~
 |  | R62 | 120 | Device:R | Resistor_SMD:R_0805_2012Metric_Pad1.20x1.40mm_HandSolder | ~
 |  | R63 | 0 | Device:R | Resistor_SMD:R_0805_2012Metric_Pad1.20x1.40mm_HandSolder | ~
 |  | R64 | 68 | Device:R | Resistor_SMD:R_0805_2012Metric_Pad1.20x1.40mm_HandSolder | ~
 |  | R65 | 10k | Device:R | Resistor_SMD:R_0805_2012Metric_Pad1.20x1.40mm_HandSolder | ~
 |  | R66 | 330k | Device:R | Resistor_SMD:R_0805_2012Metric_Pad1.20x1.40mm_HandSolder | ~
 |  | R67 | 470k | Device:R | Resistor_SMD:R_0805_2012Metric_Pad1.20x1.40mm_HandSolder | ~
 |  | R68 | 100k | Device:R | Resistor_SMD:R_0805_2012Metric_Pad1.20x1.40mm_HandSolder | ~
 |  | R69 | 10M | Device:R | Resistor_SMD:R_0805_2012Metric_Pad1.20x1.40mm_HandSolder | ~
 |  | RV1 | 1M | Device:R_Potentiometer_Trim | mylib:Potentiometer_Bourns_PV36W_Vertical | ~
 |  | SW3 | SW_Push | Switch:SW_Push | Button_Switch_THT:SW_Tactile_SPST_Angled_PTS645Vx83-2LFS | ~
 |  | SW4 | SW_SLLB5 | mylib:SW_SLLB5 | mylib:SW_SLLB510100_handsolder | https://tech.alpsalpine.com/prod/e/html/multicontrol/switch/sllb5/sllb510100.html
 |  | U1 | ATtiny3226-SU | MCU_Microchip_ATtiny:ATtiny3216-S | Package_SO:SOIC-20W_7.5x12.8mm_P1.27mm | http://ww1.microchip.com/downloads/en/DeviceDoc/ATtiny3216_ATtiny1616-data-sheet-40001997B.pdf
 |  | U2 | I2C_OLED_128x32 | mylib:I2C_OLED_128x32 | mylib:I2C_OLED_128x32
 |  | U3 | MAX4636EUB+ | mylib:MAX4636 | Package_SO:VSSOP-10_3x3mm_P0.5mm | http://www.ti.com/lit/ds/symlink/ts5a23159.pdf
 |  | U4 | DG4052EEQ-T1-GE3 | Analog_Switch:CD4052B | Package_SO:TSSOP-16_4.4x5mm_P0.65mm | http://www.ti.com/lit/ds/symlink/cd4052b.pdf
 |  | U5 | DG4052EEQ-T1-GE3 | Analog_Switch:CD4052B | Package_SO:TSSOP-16_4.4x5mm_P0.65mm | http://www.ti.com/lit/ds/symlink/cd4052b.pdf
 |  | U6 | OPA4388ID | Amplifier_Operational:OPA4340UA | Package_SO:SOIC-14_3.9x8.7mm_P1.27mm | http://www.ti.com/lit/ds/symlink/opa340.pdf
 |  | U7 | MCP1642B-33I/MS | mylib:MCP1642B | Package_SO:MSOP-8_3x3mm_P0.65mm | https://ww1.microchip.com/downloads/en/DeviceDoc/20005253A.pdf
 |  | U8 | 74AHC1G08 | 74xGxx:74AHC1G08 | Package_TO_SOT_SMD:SOT-23-5_HandSoldering | http://www.ti.com/lit/sg/scyt129e/scyt129e.pdf
 |  | U9 | MAX4636EUB+ | mylib:MAX4636 | Package_SO:VSSOP-10_3x3mm_P0.5mm | http://www.ti.com/lit/ds/symlink/ts5a23159.pdf
 |  | U10 | CH340E | Interface_USB:CH340E | Package_SO:MSOP-10_3x3mm_P0.5mm | https://www.mpja.com/download/35227cpdata.pdf
 |  | U11 | TLV9062xD | Amplifier_Operational:TLV9062xD | Package_SO:VSSOP-8_3.0x3.0mm_P0.65mm | https://www.ti.com/lit/ds/symlink/tlv9062.pdf
 |  | U12 | PCA9536D | Interface_Expansion:PCA9536D | Package_SO:SOIC-8_3.9x4.9mm_P1.27mm | http://www.nxp.com/documents/data_sheet/PCA9536.pdf
 |  | U13 | 74AUP1G02 | mylib:74AUP1G02 | Package_TO_SOT_SMD:SOT-353_SC-70-5_Handsoldering | http://www.ti.com/lit/sg/scyt129e/scyt129e.pdf
 |  | U14 | 74AUP1G02 | mylib:74AUP1G02 | Package_TO_SOT_SMD:SOT-353_SC-70-5_Handsoldering | http://www.ti.com/lit/sg/scyt129e/scyt129e.pdf
Collated Components:
Item | Qty | Reference(s) | Value | LibPart | Footprint | Datasheet
1 | 1 | BT1 | Battery_Cell | Device:Battery_Cell | Battery:BatteryHolder_Keystone_2466_1xAAA | ~
2 | 13 | C1, C8, C10, C12, C14, C15, C21, C22, C23, C26, C31, C33, C34 | 100nF | Device:C | Capacitor_SMD:C_0805_2012Metric_Pad1.18x1.45mm_HandSolder | ~
3 | 1 | C2 | 100uF 25V | Device:C | mylib:KCM55WC71E107MH13 | ~
4 | 3 | C3, C4, C5 | 100uF 6.3V | Device:C | Capacitor_SMD:C_1206_3216Metric_Pad1.33x1.80mm_HandSolder | ~
5 | 7 | C6, C7, C9, C11, C25, C32, C35 | 10uF | Device:C | Capacitor_SMD:C_0805_2012Metric_Pad1.18x1.45mm_HandSolder | ~
6 | 1 | C13 | 100pF | Device:C | Capacitor_SMD:C_0805_2012Metric_Pad1.18x1.45mm_HandSolder | ~
7 | 7 | C16, C17, C18, C19, C28, C29, C30 | 10nF | Device:C | Capacitor_SMD:C_0805_2012Metric_Pad1.18x1.45mm_HandSolder | ~
8 | 2 | C20, C24 | 1uF | Device:C | Capacitor_SMD:C_0805_2012Metric_Pad1.18x1.45mm_HandSolder | ~
9 | 1 | C27 | 33pF | Device:C | Capacitor_SMD:C_0805_2012Metric_Pad1.18x1.45mm_HandSolder | ~
10 | 1 | D1 | MMBZ20VAL,215 | Diode:MMBZxx | Package_TO_SOT_SMD:SOT-23 | http://www.onsemi.com/pub/Collateral/MMBZ5V6ALT1-D.PDF
11 | 3 | D2, D6, D7 | VESD03C1-02V | Device:D_Zener | Diode_SMD:D_SOD-523 | ~
12 | 1 | D4 | 1N4148 | Diode:1N4148 | Diode_SMD:D_SOD-123 | https://assets.nexperia.com/documents/data-sheet/1N4148_1N4448.pdf
13 | 1 | D5 | LED | Device:LED | LED_SMD:LED_1206_3216Metric_Pad1.42x1.75mm_HandSolder | ~
14 | 3 | F1, F2, F3 | PTC 100mA | Device:Polyfuse | Fuse:Fuse_1206_3216Metric_Pad1.42x1.75mm_HandSolder | ~
15 | 1 | F4 | Polyfuse | Device:Polyfuse | Fuse:Fuse_1206_3216Metric_Pad1.42x1.75mm_HandSolder | ~
16 | 1 | J1 | Conn_01x02_Female | Connector:Conn_01x02_Female | Connector_PinSocket_2.54mm:PinSocket_1x02_P2.54mm_Horizontal | ~
17 | 1 | J2 | Conn_01x04_Male | Connector:Conn_01x04_Male | Connector_JST:JST_XH_B4B-XH-A_1x04_P2.50mm_Vertical | ~
18 | 1 | J3 | USB_B_Micro | Connector:USB_B_Micro | mylib:USB_Micro-B_mine | ~
19 | 1 | J4 | Conn_01x11_Male | Connector:Conn_01x11_Male | Connector_PinHeader_2.54mm:PinHeader_1x11_P2.54mm_Vertical | ~
20 | 2 | J5, J9 | Conn_01x02_Male | Connector:Conn_01x02_Male | Connector_PinHeader_2.54mm:PinHeader_1x02_P2.54mm_Vertical | ~
21 | 1 | J6 | Conn_01x03_Male | Connector:Conn_01x03_Male | Connector_PinHeader_2.54mm:PinHeader_1x03_P2.54mm_Vertical | ~
22 | 1 | JP1 | Jumper_2_Bridged | Jumper:Jumper_2_Bridged | Jumper:SolderJumper-2_P1.3mm_Bridged_Pad1.0x1.5mm | ~
23 | 1 | L1 | 4.7uH Shld | Device:L_Ferrite | mylib:L_Coilcraft_LPS4018 | ~
24 | 2 | Q1, Q2 | DMN62D0UDW-13 | Transistor_FET:FDG1024NZ | Package_TO_SOT_SMD:SOT-363_SC-70-6 | https://www.onsemi.com/pub/Collateral/FDG1024NZ-D.pdf
25 | 1 | R1 | 50mOhm precision | Device:R_Shunt | mylib:R_Shunt_Ohmite_LVK12_ALT | ~
26 | 1 | R2 | 0.5 Ohm precision | Device:R_Shunt | mylib:R_1206_3216Metric_4Wire | ~
27 | 1 | R3 | 5 Ohm precision | Device:R_Shunt | mylib:R_1206_3216Metric_4Wire | ~
28 | 1 | R4 | 45 Ohm precision | Device:R_Shunt | mylib:R_1206_3216Metric_4Wire | ~
29 | 5 | R5, R8, R18, R19, R69 | 10M | Device:R | Resistor_SMD:R_0805_2012Metric_Pad1.20x1.40mm_HandSolder | ~
30 | 10 | R6, R9, R28, R29, R31, R41, R42, R45, R60, R68 | 100k | Device:R | Resistor_SMD:R_0805_2012Metric_Pad1.20x1.40mm_HandSolder | ~
31 | 5 | R7, R34, R35, R38, R40 | 1k | Device:R | Resistor_SMD:R_0805_2012Metric_Pad1.20x1.40mm_HandSolder | ~
32 | 1 | R10 | 220 | Device:R | Resistor_SMD:R_0805_2012Metric_Pad1.20x1.40mm_HandSolder | ~
33 | 5 | R11, R46, R47, R61, R65 | 10k | Device:R | Resistor_SMD:R_0805_2012Metric_Pad1.20x1.40mm_HandSolder | ~
34 | 1 | R12 | 470 | Device:R | Resistor_SMD:R_0805_2012Metric_Pad1.20x1.40mm_HandSolder | ~
35 | 2 | R13, R48 | 4k7 | Device:R | Resistor_SMD:R_0805_2012Metric_Pad1.20x1.40mm_HandSolder | ~
36 | 3 | R14, R15, R39 | 1M | Device:R | Resistor_SMD:R_0805_2012Metric_Pad1.20x1.40mm_HandSolder | ~
37 | 2 | R16, R17 | 270 | Device:R | Resistor_SMD:R_0805_2012Metric_Pad1.20x1.40mm_HandSolder | ~
38 | 2 | R20, R21 | 47 | Device:R | Resistor_SMD:R_0805_2012Metric_Pad1.20x1.40mm_HandSolder | ~
39 | 13 | R22, R23, R24, R49, R50, R51, R52, R54, R55, R56, R57, R59, R63 | 0 | Device:R | Resistor_SMD:R_0805_2012Metric_Pad1.20x1.40mm_HandSolder | ~
40 | 4 | R25, R26, R27, R36 | 47k | Device:R | Resistor_SMD:R_0805_2012Metric_Pad1.20x1.40mm_HandSolder | ~
41 | 1 | R30 | 8k2 | Device:R | Resistor_SMD:R_0805_2012Metric_Pad1.20x1.40mm_HandSolder | ~
42 | 1 | R32 | 82k | Device:R | Resistor_SMD:R_0805_2012Metric_Pad1.20x1.40mm_HandSolder | ~
43 | 1 | R33 | 15k | Device:R | Resistor_SMD:R_0805_2012Metric_Pad1.20x1.40mm_HandSolder | ~
44 | 1 | R37 | 100 | Device:R | Resistor_SMD:R_1206_3216Metric_Pad1.30x1.75mm_HandSolder | ~
45 | 1 | R43 | 9M1 1% | Device:R | Resistor_SMD:R_0805_2012Metric_Pad1.20x1.40mm_HandSolder | ~
46 | 1 | R44 | 1M 1% | Device:R | Resistor_SMD:R_0805_2012Metric_Pad1.20x1.40mm_HandSolder | ~
47 | 2 | R53, R64 | 68 | Device:R | Resistor_SMD:R_0805_2012Metric_Pad1.20x1.40mm_HandSolder | ~
48 | 2 | R58, R62 | 120 | Device:R | Resistor_SMD:R_0805_2012Metric_Pad1.20x1.40mm_HandSolder | ~
49 | 1 | R66 | 330k | Device:R | Resistor_SMD:R_0805_2012Metric_Pad1.20x1.40mm_HandSolder | ~
50 | 1 | R67 | 470k | Device:R | Resistor_SMD:R_0805_2012Metric_Pad1.20x1.40mm_HandSolder | ~
51 | 1 | RV1 | 1M | Device:R_Potentiometer_Trim | mylib:Potentiometer_Bourns_PV36W_Vertical | ~
52 | 1 | SW3 | SW_Push | Switch:SW_Push | Button_Switch_THT:SW_Tactile_SPST_Angled_PTS645Vx83-2LFS | ~
53 | 1 | SW4 | SW_SLLB5 | mylib:SW_SLLB5 | mylib:SW_SLLB510100_handsolder | https://tech.alpsalpine.com/prod/e/html/multicontrol/switch/sllb5/sllb510100.html
54 | 1 | U1 | ATtiny3226-SU | MCU_Microchip_ATtiny:ATtiny3216-S | Package_SO:SOIC-20W_7.5x12.8mm_P1.27mm | http://ww1.microchip.com/downloads/en/DeviceDoc/ATtiny3216_ATtiny1616-data-sheet-40001997B.pdf
55 | 1 | U2 | I2C_OLED_128x32 | mylib:I2C_OLED_128x32 | mylib:I2C_OLED_128x32
56 | 2 | U3, U9 | MAX4636EUB+ | mylib:MAX4636 | Package_SO:VSSOP-10_3x3mm_P0.5mm | http://www.ti.com/lit/ds/symlink/ts5a23159.pdf
57 | 2 | U4, U5 | DG4052EEQ-T1-GE3 | Analog_Switch:CD4052B | Package_SO:TSSOP-16_4.4x5mm_P0.65mm | http://www.ti.com/lit/ds/symlink/cd4052b.pdf
58 | 1 | U6 | OPA4388ID | Amplifier_Operational:OPA4340UA | Package_SO:SOIC-14_3.9x8.7mm_P1.27mm | http://www.ti.com/lit/ds/symlink/opa340.pdf
59 | 1 | U7 | MCP1642B-33I/MS | mylib:MCP1642B | Package_SO:MSOP-8_3x3mm_P0.65mm | https://ww1.microchip.com/downloads/en/DeviceDoc/20005253A.pdf
60 | 1 | U8 | 74AHC1G08 | 74xGxx:74AHC1G08 | Package_TO_SOT_SMD:SOT-23-5_HandSoldering | http://www.ti.com/lit/sg/scyt129e/scyt129e.pdf
61 | 1 | U10 | CH340E | Interface_USB:CH340E | Package_SO:MSOP-10_3x3mm_P0.5mm | https://www.mpja.com/download/35227cpdata.pdf
62 | 1 | U11 | TLV9062xD | Amplifier_Operational:TLV9062xD | Package_SO:VSSOP-8_3.0x3.0mm_P0.65mm | https://www.ti.com/lit/ds/symlink/tlv9062.pdf
63 | 1 | U12 | PCA9536D | Interface_Expansion:PCA9536D | Package_SO:SOIC-8_3.9x4.9mm_P1.27mm | http://www.nxp.com/documents/data_sheet/PCA9536.pdf
64 | 2 | U13, U14 | 74AUP1G02 | mylib:74AUP1G02 | Package_TO_SOT_SMD:SOT-353_SC-70-5_Handsoldering | http://www.ti.com/lit/sg/scyt129e/scyt129e.pdf

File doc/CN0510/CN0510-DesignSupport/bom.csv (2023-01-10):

TITLE: Bill of Materials
BOM NO: 05-047456-01-e.csv
DATE: 08/16/2019
DESIGN: 02_047456e_top
TEMPLATE: Z:\allegro\v172_site\cdssetup\template.bom
CALLOUT: C:\tmp\20_047456e\worklib\02_047456e_top\bom\bom.callouts
ITEM# | Qty | WW_PN | DESCRIPTION | VALUE | JEDEC_TYPE | TOL | VOLTAGE | WATTAGE | LOCATION | MFG | MFG_PN | HLM_STATUS | STOCKROOM_WL | STOCKROOM_GT | STOCKROOM_LK | STOCKROOM_GBO | STOCKROOM_NSH | CUSTOM_PART | DNI
1 | 1 | 08-047456d | PCB | ? | ? | ? | ? | ? | ? | Analog Devices Supplied | 08-047456d | N/A | ? | ? | ? | ? | ? | ? | ?
2 | 1 | E017939 | IC-ADI LOW COST LOW NOISE CMOS RRO OP AMP | AD8694ARZ | SO14NB-2 | N/A | N/A | ? | A2 | ANALOG DEVICES | AD8694ARZ | REL | N/A | N/A | N/A | N/A | N/A | ? | ?
3 | 7 | E016321 | CONN-PCB TEST POINT YELLOW | YEL | CNKEY5001TP | N/A | N/A | N/A | AIN1,CE0,EXC_P,SNS_N,SNS_P,TP1,TP3 | KEYSTONE ELECTRONICS | 5004 | REL | N/A | N/A | N/A | N/A | 6001623 | ? | ?
4 | 7 | E024444 | CAP CER X7R, AC VOLT LOW CAP CHANGE RATE | 1UF | C0603 | 10 | 10V | N/A | C9,C10,C11,C13,C20,C30,C32 | KEMET | C0603C105K8RACTU | REL | N/A | N/A | N/A | N/A | N/A | ? | ?
5 | 6 | E014704 | CAP CER X5R, GENERAL PURPOSE | 10uF | C0805H60 | 10 | 25V | N/A | C7,C12,C14,C15,C16,C17 | MURATA | GRM21BR61E106KA73L | REL | N/A | N/A | N/A | N/A | 7002498 | ? | ?
6 | 2 | E018426 | CAP CER NP0 | 6.8pF | C0805 | 0.25pF | 50V | N/A | C21,C22 | KEMET | C0805C689C5GACTU | REL | N/A | N/A | N/A | N/A | 7003407 | ? | ?
7 | 3 | E026762 | CAP CER X5R, GENERAL PURPOSE | 10UF | C0603 | 20 | 35V | N/A | C25,C27,C29 | MURATA | GRM188R6YA106MA73D | REL | N/A | N/A | N/A | N/A | N/A | ? | ?
8 | 2 | E025743 | CAP CER X7R, AUTOMOTIVE GRADE | 1UF | C0603 | 10 | 25V | N/A | C26,C28 | TDK | CGA3E1X7R1E105K080AD | REL | N/A | N/A | N/A | N/A | N/A | ? | ?
9 | 6 | E010425 | CAP MULTILAYER CER X5R 0805 | 2.2uF | C0805 | 10 | 10V | N/A | C5,C6,C36,C37,C38,C39 | TAIYO YUDEN | LMK212BJ225KD-T | REL | N/A | N/A | N/A | N/A | 7002770 | ? | ?
10 | 1 | E000415 | CAP CER NP0 | 100PF | C0603 | 5 | 50V | N/A | C8 | PHYCOMP (YAGEO) | 2238 867 15101 | REL | A004-0012-075 | N/A | 722080 | N/A | 7002399 | ? | ?
11 | 4 | E023533 | CONN-PCB BNC JACK RA 75OHM | 112809-75 | CNBNCRAL1098W550H474 | N/A | N/A | N/A | F+,F-,S+,S- | AMPHENOL | 112809-75 | REL | N/A | N/A | N/A | N/A | N/A | ? | ?
12 | 1 | E019415 | LED LOW CURRENT (RED) | SML-P11VTT86 | LED0402 | N/A | N/A | 0.050W | GP1 | ROHM | SML-P11VTT86 | REL | N/A | N/A | N/A | N/A | N/A | ? | ?
14 | 1 | E028415 | RES JUMPER | 0 | R0805 | N/A | N/A | 1/2W | JP3 | KEYSTONE | 5106 | REL | N/A | N/A | N/A | N/A | N/A | ? | ?
15 | 1 | E021002 | CONN-PCB HDR JMPR, 1X M000385 | 22-03-2031 | CNHDR1X3H530 | N/A | N/A | N/A | JP7 | MOLEX | 22-03-2031 | REL | N/A | N/A | N/A | N/A | N/A | ? | ?
16 | 2 | E023091 | CONN-PCB HDR SIL VERT, 2.0MM PITCH | M22-2010205 | CNHDR1X2H207 | N/A | N/A | N/A | P1,P8 | HARWIN | M22-2010205 | REL | N/A | N/A | N/A | N/A | N/A | ? | ?
17 | 1 | E020477 | CONN-PCB RCPT 25MIL SQ POST 2.54MM PITCH | SSQ-106-03-G-S | CNSAMTECSSQ-106-XX-X-S | N/A | N/A | N/A | P2 | SAMTEC | SSQ-106-03-G-S | REL | N/A | N/A | N/A | N/A | N/A | ? | ?
18 | 2 | E020478 | CONN-PCB RCPT 25MIL SQ POST 2.54MM P | SSQ-108-03-G-S | CNSAMTECSSQ-108-XX-X-S | N/A | N/A | N/A | P3,P6 | SAMTEC | SSQ-108-03-G-S | REL | N/A | N/A | N/A | N/A | N/A | ? | ?
20 | 1 | E020479 | CONN-PCB RCPT 25MIL SQ POST 2.54MM PITCH | SSQ-110-03-G-S | CNSAMTECSSQ-110-XX-X-S | N/A | N/A | N/A | P5 | SAMTEC | SSQ-110-03-G-S | REL | N/A | N/A | N/A | N/A | N/A | ? | ?
21 | 1 | E013453 | CONN-PCB 2POS TERM BLOCK, 5.08MM PITCH, 3.5MM SOLDER TAIL | EDZ250/2 | CNTH1X2H394 | N/A | N/A | N/A | P7 | ON-SHORE TECHNOLOGY | EDZ250/2 | REL | N/A | N/A | N/A | N/A | N/A | ? | ?
22 | 1 | E014445 | LED LOW CURRENT (GREEN) | SML-P11MTT86RR | LED0402 | N/A | N/A | 0.054W | PWR | ROHM | SML-P11MTT86R | REL | N/A | N/A | N/A | N/A | N/A | ? | ?
23 | 1 | E017741 | TRAN NPN GEN PURPOSE AMPLIFIER | 2N3904TF | TO92V2 | N/A | 40V | N/A | Q1 | FAIRCHILD SEMICONDUCTOR | 2N3904TF | REL | N/A | N/A | N/A | N/A | 1001254 | ? | ?
24 | 1 | E005562 | TRANSISTOR TIP31BG NPN TO-220 | TIP31BG | TO220 | N/A | N/A | N/A | Q2 | ON SEMICONDUCTOR | TIP31BG | REL | ADD_TO_STOCK_39 | 42005JH130 | N/A | N/A | 1006080 | ? | ?
25 | 2 | E004245 | RES THICK FILM CHIP | 560 | R0603 | 1 | N/A | 1/16W | R1,R42 | MULTICOMP (SPC) | MC0063W06031560R | REL | N/A | N/A | N/A | N/A | N/A | ? | ?
26 | 2 | E003254 | RES PRECISION THICK FILM CHIP | 10K | R0805 | 1 | N/A | 1/8W | R10,R33 | PANASONIC | ERJ-6ENF1002V | REL | A003-0018-083 | 41816JH359 | FEC 911-975 | 116_CAB3 | N/A | ? | ?
27 | 1 | E017856 | RES THICK FILM CHIP | 10K | R0603 | 1 | N/A | 1/16W | R11 | MULTICOMP (SPC) | MC0063W0603110K | REL | N/A | N/A | N/A | N/A | N/A | ? | ?
28 | 2 | E003811 | RES METAL FILM CHIP, FOR SM-TH COMBO FOOTPRINT USE ALT_SYMBOLS | 1K | R0805 | 0.1 | N/A | 1/8W | R12,R27 | PANASONIC | ERA-6AEB102V | REL | A003-0036-014 | N/A | FEC 554-005 | N/A | N/A | ? | ?
29 | 4 | E003806 | RES THIN FILM CHIP, HIGH RELIABILITY | 10K | R0805 | 0.1 | N/A | 1/8W | R13,R14,R28,R29 | PANASONIC | ERA-6AEB103V | REL | N/A | N/A | N/A | N/A | 7001467 | ? | ?
30 | 1 | E014042 | RES STD THICK FILM CHIP | 17.4K | R0402 | 1 | N/A | 1/16W | R15 | VISHAY | CRCW040217K4FKED | REL | N/A | N/A | N/A | 1594_CAB3 | 7006318 | ? | ?
31 | 1 | E019640 | RES STD THICK FILM CHIP | 10K | R0402 | 5 | N/A | 1/16W | R16 | VISHAY | CRCW040210K0JNED | REL | N/A | N/A | N/A | N/A | 7000280 | ? | ?
32 | 6 | E004152 | RES THIN FILM CHIP | 0 | R0805 | N/A | N/A | 1/10W | R17,R20,R22,R32,R38,R39 | MULTICOMP (SPC) | MC 0.1W 0805 0R | REL | N/A | N/A | N/A | N/A | 7005370 | ? | ?
33 | 6 | E030617 | RES PRECISION THIN FILM CHIP | 2MEG | R0805 | 0.1 | N/A | 1/10W | R2,R3,R4,R5,R18,R19 | TE CONNECTIVITY | CPF0805B2M0E1 | REL | N/A | N/A | N/A | N/A | N/A | ? | ?
34 | 1 | E004198 | RES FILM SMD 0805 | 62 | R0805 | 5 | N/A | 1/10W | R21 | MULTICOMP (SPC) | MC 0.1W 0805 5% 62R. | REL | ADD_TO_STOCK_143 | N/A | 771-193 | N/A | 7008206 | ? | ?
35 | 1 | E014707 | RES PRECISION THICK FILM CHIP | 51 | R0805 | 1 | N/A | 1/8W | R25 | PANASONIC | ERJ-6ENF51R0V | REL | N/A | N/A | N/A | N/A | 7007982 | ? | ?
36 | 1 | E023447 | RES THICK FILM CHIP | 470 | R0805 | 1 | 150V | 1/3W | R26 | VISHAY | CRCW0805470RFKEAHP | REL | N/A | N/A | N/A | N/A | N/A | ? | ?
37 | 1 | E003438 | RES CHIP SMD JMPR | 0 | R0402 | 5 | N/A | N/A | R34 | PANASONIC | ERJ-2GE0R00X | REL | A003-0021-001 | N/A | N/A | 1138_CAB3 | 7000282 | ? | ?
39 | 5 | E003415 | RES PRECISION THICK FILM CHIP | 1K | R0805 | 1 | N/A | 1/8W | R6,R7,R8,R9,R36 | PANASONIC | ERJ-6ENF1001V | REL | A003-0019-008 | 41816DG204 | FEC 911-859 | 613_CAB3 | N/A | ? | ?
40 | 2 | E004207 | RES FILM SMD 0603 | 0 | R0603 | 1 | N/A | 1/16W | R40,R41 | MULTICOMP (SPC) | MC0603WG00000T5E-TC | REL | A003-0032-130 | N/A | 772-227 | N/A | N/A | ? | ?
41 | 1 | E025935 | RES METAL FOIL CURRENT SENSING, TWO TERMINAL | 0.05 | R2512_6P_RSENSE | 1 | 200V | 2W | RCAL | MULTICOMP | MCLRP12DTDRR050 | REL | N/A | N/A | N/A | N/A | N/A | ? | ?
42 | 1 | E004572 | SW SM MECHANICAL KEYSWITCH | B3S-1000 | SWB3S1000 | N/A | N/A | N/A | RESET | OMRON | B3S1000 | REL | A007-0004-019 | 41916JH036 | N/A | N/A | 6003207 | ? | ?
43 | 1 | E027951 | HIGH PRECISION,BIO-IMPERDAMCE AMD ELECTROCHEMICAL FRONT END PRELIM | AD5941BCPZ | QFN48_7X7_PAD5_1X5_1 | N/A | N/A | ? | U1 | ANALOG DEVICES | AD5941BCPZ-RL7 | RWC | N/A | N/A | N/A | N/A | N/A | ? | ?
44 | 1 | E011813 | IC CMOS DUAL SPDT SWITCH | ADG636YRUZ | TSSOP14 | N/A | N/A | ? | U2 | ADI | ADG636YRUZ | REL | N/A | N/A | N/A | N/A | 1003399 | ? | ?
45 | 1 | E022406 | IC-ADI 600MA, ULTRALOW NOISE, HIGH PSRR, RF LINEAR REG, 1.2 TO 3.4 VOUT | ADM7155ARDZ-04 | SO8NB-PAD2_3X2_3 | N/A | N/A | ? | U3 | ANALOG DEVICES | ADM7155ARDZ-04-R7 | REL | N/A | N/A | N/A | N/A | N/A | ? | ?
47 | 1 | E029612 | IC CRYSTAL ULTRA MINIATURE CERAMIC SMD | 16MEGHZ | YSML126W98H31 | 10PPM | N/A | N/A | Y1 | ABRACON CORP. | ABM8-16.000MHZ-7-1-U-T | REL | N/A | N/A | N/A | N/A | N/A | ? | ?
Callouts File:C:\tmp\20_047456e\worklib\02_047456e_top\bom\bom.callouts
Mechanical Parts
ITEM# | Qty | WW_PN | DESCRIPTION | VALUE | JEDEC_TYPE | TOL | VOLTAGE | WATTAGE | LOCATION | MFG | MFG_PN | HLM_STATUS | STOCKROOM_WL | STOCKROOM_GT | STOCKROOM_LK | STOCKROOM_GBO | STOCKROOM_NSH | CUSTOM_PART | DNI
2 | 1 | M029337 | JUMPER OPEN TOP, 2.54MM CONTACT CENTER, BLACK | ? | N/A | ? | ? | ? | ? | SULLINS | QPC02SXGN-RC | REL | N/A | N/A | N/A | N/A | N/A | ? | ?
The following components are part of the PCB or are NOT to be installed
ITEM# | Qty | WW_PN | DESCRIPTION | VALUE | JEDEC_TYPE | TOL | VOLTAGE | WATTAGE | LOCATION | MFG | MFG_PN | HLM_STATUS | STOCKROOM_WL | STOCKROOM_GT | STOCKROOM_LK | STOCKROOM_GBO | STOCKROOM_NSH | CUSTOM_PART | DNI
13 | 4 | E021002 | CONN-PCB HDR JMPR, 1X M000385 | 22-03-2031 | CNHDR1X3H530 | N/A | N/A | N/A | JP1,JP2,JP8,JP9 | MOLEX | 22-03-2031 | REL | N/A | N/A | N/A | N/A | N/A | ? | DNI
19 | 1 | E017614 | CONN-PCB HDR 2.54MM PITCH SIL VERT PC TAIL | M20-9990345 | CNHDR1X3H340 | N/A | N/A | N/A | P4 | HARWIN | M20-9990345 | REL | N/A | N/A | N/A | N/A | 6002138 | ? | DNI
38 | 2 | E004207 | RES FILM SMD 0603 | 0 | R0603 | 1 | N/A | 1/16W | R35,R37 | MULTICOMP (SPC) | MC0603WG00000T5E-TC | REL | A003-0032-130 | N/A | 772-227 | N/A | N/A | ? | DNI
46 | 1 | E020447 | IC-ADI 4-CH MULTIPLEXER | ADG1609BCPZ | QFN16_3X3_PAD1_6X1_6 | N/A | N/A | ? | U4 | ANALOG DEVICES | ADG1609BCPZ-REEL7 | REL | N/A | N/A | N/A | N/A | N/A | ? | DNI

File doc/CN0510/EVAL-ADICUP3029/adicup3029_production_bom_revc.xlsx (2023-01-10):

No. | Mfg. | Mfr Part Number | DESC | Qty | Reference Designator
1 | Analog Devices | 08_044136c | PCB | 1
2 | ABRACON CORP | AMCA31-2R450G-S1F-T | ANTENNA WLAN/BLUETOOTH CHIP | 1 | ANT1
3 | MEMORY PROTECTION DEVICES, INC. | BC2AAAPC | SOCKET, TWO AAA BATTERY HOLDER WITH PC PINS | 1 | BT1
4 | KEMET CORPORATION | T491A106M020AT | CAP TANT CHIP | 3 | C1,C6,C9
5 | YAGEO | CC0603JRNPO9BN330 | CAP CER NP0 | 1 | C10
6 | Samsung | CL10A226MP8NUNE | CAP CER X5R, 22uF 10V 0603 | 1 | C11
7 | Samsung | CL10A106KP8NNND | CAP CER 10UF 10V X5R 0603 | 2 | C12,C45
8 | Samsung | CL10B105KO8NNNC | CAP,1UF,+/-10%,X7R,16V,SMD0603 | 8 | C2,C7,C13,C14,C23,C32,C34,C43
9 | Samsung | CL10A475KO8NNNC | CAP CER X5R, 4.7uF 16V 0603 | 8 | C4,C5,C15,C16,C19,C36,C51,C53
10 | Samsung | CL10B104KO8NNNC | CAP,100NF,+/-10%,X7R,16V,SMD0603 | 12 | C3,C17,C18,C20,C21,C22,C31,C33,C35,C47,C48,C52
11 | Samsung | CL10C180JB8NNNC | CAP CER C0G(NP0), 18pF 50V 0603 | 2 | C24,C25
12 | Samsung | CL10B225KP8NNNC | CAP CER X7R, 2.2uF 10V 0603 | 3 | C26,C44,C46
13 | Samsung | CL10C100JB8NNNC | CAP CER C0G(NP0), 10pF 50V 0603 | 2 | C27,C28
14 | Samsung | CL10C120JB8NNNC | CAPACITOR,12pF 50V C0G +-5%,0603,TR | 2 | C29,C30
15 | MURATA | GQM1885C2A1R2BB01D | CAP CER C0G(NP0), 1.2pF 100V 0603 | 1 | C42
16 | Samsung | CL10B474KA8NNNC | CAP CER X7R, 0.47uF 25V 0603 | 2 | C49,C50
17 | YAGEO | CC0603JRNPO9BN680 | CAP CER C0G(NP0), 68pF 50V 0603 | 1 | C8
18 | FAIRCHILD SEMICONDUCTOR | BAT54A | DIODE SHTKY DUAL COM ANOD | 1 | CR1
19 | DIODES INCORPORATED | 1N5819HW-7-F | DIODE SCHOTTKY BARRIER RECT | 1 | D1
20 | EVERLIGHT AMERICAS INC. | 19-217/GHC-YR1S2/3T | LED UNICOLOR GREEN 518NM | 2 | DS1,DS3
21 | EVERLIGHT AMERICAS INC. | 19-217/S2C-AL1M2VY/3T | LED BRILLIANT ORANGE 611NM | 1 | DS2
22 | EVERLIGHT AMERICAS INC. | 19-217/BHC-ZL1M2RY/3T | LED BLUE 468NM | 1 | DS4
23 | MURATA | BLM18KG221SN1D | 220 OHM IND FERRITE BD | 2 | E1,E3
24 | MURATA | BLM15HG601SN1D | IND CHIP FERRITE BEAD, 0.3A 0.7OHM DCR | 1 | E2
25 | MURATA | LQM21PN4R7MGRD | IND POWER COIL | 6 | L1,L2,L3,L4,L5,L7
26 | MURATA MANUFACTURING | LQG15HN4N3S02D | IND SM CHIP COILS | 1 | L6
27 | SULLINS | PPTC042LFBN-RC | CONN-PCB 8POS FEMALE HDR, 100MILS PITCH, ACCEPTS 25MILS SQ POSTS, SOLDER TAIL 126MILS | 1 | P1
28 | MOLEX | 47346-0001 | CONN-PCB MICROUSB RECEPTACLE | 1 | P10
29 | MTCONN | P127-100-D2-205-001 | Connector,pin header,straight,male,2x5pin,1.27mm pitch,3.00,2.30,Gold flash 1u,black,dip | 3 | P11,P12,P14
30 | MTCONN | JTP254-D180-102-02L | pin header,2.54p,1x2pos,5.08H,5.84T,GF,Dip | 2 | P15,P18
31 | NS-Tech | 1125R-4P | CONN-PCB 4POS SHROUDED RA HDR DISCONNECTABLE CRIMP STYLE, WIRE-TO-BRD SIDE ENTRY, 3.4MM SOLDER TAIL LENGTH, 2MM PITCH | 1 | P19
32 | CUI | PJ-102AH | CONN-PCB DC POWER JACK TH | 1 | P2
33 | MTCONN | JT254F-D180-850-106-10DO-G | Connector,Pin Socket,Straight,Female,1x6Pin,2.54MM pitch,8.5,9.92,Gold Flash 1u, black,DIP | 1 | P3
34 | MTCONN | JT254F-D180-850-108-10DO-G | Connector,Pin Socket,Straight,Female,1x8Pin,2.54MM pitch,8.5,9.92,Gold Flash 1u, black,DIP | 2 | P4,P7
35 | AMPHENOL FCI | 67996-406HLF | CONN-PCB UNSHROUDED HDR DUAL ROW ST, 2.41MM SOLDER TAIL, 2.54MM PITCH | 1 | P5
36 | MTCONN | JT254F-D180-850-110-10DO-G | Connector,Pin Socket,Straight,Female,1x10Pin,2.54MM pitch,8.5,9.92,Gold Flash 1u, black,DIP | 1 | P6
37 | MTCONN | JT254F-D90-850-206-01 | Connector,Pin Socket,Right Angle,Female,2x6Pin,2.54MM pitch,8.5,3.2,Gold flash,black,DIP | 1 | P8
38 | MTCONN | JT254F-D90-850-204-01 | pin socket,right angle,2.54pitch,2x4pin,dip,8.5H,3.2T | 1 | P9
39 | INFINEON TECHNOLOGIES AG | IRLML6401TRPBF | TRAN P-CH POWER MOSFET | 1 | Q1
40 | YAGEO | RC0603FR-072K7L |  | 2 | R48,R49
41 | YAGEO | RC0603JR-070RL | RES THICK FILM 0 OHM 1/10W 0603 | 7 | R10,R29,R30,R31,R32,R39,R40
42 | YAGEO | RC0603FR-074K7L | RES THICK FILM 4.7K OHM 1/10W 0603 | 2 | R11,R15
43 | YAGEO | RC0603FR-0710KL | RES THICK FILM 10K OHM 1/10W 0603 | 10 | R1,R12,R16,R17,R20,R21,R24,R28,R42,R50
44 | YAGEO | RC0805FR-0733RL | RES THICK FILM 33 OHM 1/8W 0603 | 2 | R13,R14
45 | YAGEO | RC0603FR-0722KL | RES THICK FILM 22K OHM 1/10W 0603 | 2 | R2,R3
46 | MULTICOMP | MC0063W06031330R | RES THICK FILM 330 OHM 1/16W 0603 | 10 | R8,R22,R23,R25,R33,R34,R35,R36,R37,R38
47 | YAGEO | RC0603FR-071ML | RES THICK FILM 1M OHM 1/10W 0603 | 1 | R4
48 | YAGEO | RC0603FR-07316KL | RES THICK FILM 316K OHM 1/10W 0603 | 1 | R5
49 | YAGEO | RC0603FR-07499KL | RES THICK FILM 499K OHM 1/10W 0603 | 1 | R6
50 | YAGEO | RC0603FR-07287KL | RES THICK FILM 287K OHM 1/10W 0603 | 1 | R7
51 | YAGEO | RC0603FR-071R6L | RES THICK FILM 1.6 OHM 1/10W 0603 | 1 | R9
52 | TE CONNECTIVITY LTD | FSM2JSMA | SWITCH TACT SPST NO | 3 | S1,S3,S4
53 | C&K | JS203011CQN | SWITCH SLIDE DP3T 300MA 6V | 1 | S2
54 | C&K | JS202011CQN | SWITCH SLIDE DPDT 300MA 6V | 1 | S5
55 | ADI | ADP7105ARDZ-5.0 | IC-ADI 500mA, LOW NOISE LDO REG WITH SOFT START | 1 | U1
56 | LINEAR TECHNOLOGY | LTC3528EDDB#TRMPBF | IC 1A, 1MEGHZ SYNCHRONOUS STE-UP DC/DC CONVERTER | 2 | U2,U3
57 | ADI | ADP124ARHZ-3.3-R7 | IC-ADI CMOS LOW QUIESCENT CURRENT | 1 | U4
58 | NXP SEMICONDUCTORS | MK20DX128VFM5 | IC KINETIS K 32BIT, ARM CORTEX-M4 CORE, 128KB FLASH | 1 | U5
59 | TEXAS INSTRUMENTS | SN74LVC125APW | IC-TTL QUAD BUFFER WITH 3-STATE OUTPUTS | 1 | U6
60 | ANALOG DEVICES | ADUCM3029BCPZ | IC-ADI MIXED-SIGNAL CNTRL PROCESSOR WITH ARM CORTEX-M3 (256K) PRELIM | 1 | U7
61 | EM MICROELECTRONIC | EM9304V01LF28B+ | IC OPTIMIZED BLUETOOTH V4.2 LOW-ENERGY COMPANION, PRELIM | 1 | U8
62 | NDK | NX3225SA-26.000000MHz-G2 | IC CRYSTAL FUNDAMENTAL | 1 | Y1
63 | Interquip | 9CAA32768122TF70QT | Crystal, 32.768kHz, 12.5pF, 3.2x1.5x0.9mm, 20ppm, -40~85, 70Kohm(max), SMD-2 | 2 | Y2,Y5
64 | Interquip | 5XBB08000182TF80Q3 | SMCE-5032 2PADS, 8MHZ, 18PF, +/-20PPM@25C, +/-30PPM(-40~+85C), 80ohm Max | 1 | Y3
65 | Interquip | 5YAA48000081KF50Q1 | SMCE-3225, 48MHz, 8pF, +/-10ppm@25C, +/-10ppm(-20~+70C), 50ohm Max | 1 | Y4
66 | VISHAY PRECISION GROUP | CRCW060349K9FKEAHP | RES PULSE PROOF, HP THICK FILM CHIP, 49.9K,R0603,1/4W | 1 | R41
66 | YAGEO | RC0603FR-0749K9L | RES SMD 49.9K OHM 1% 1/10W 060 | 1 | R41
 | Mechanical Parts
67 | FCI | 68786-302LF | SHUNT, 2POS .100 LOPRO TIN | 2 | P15, P18

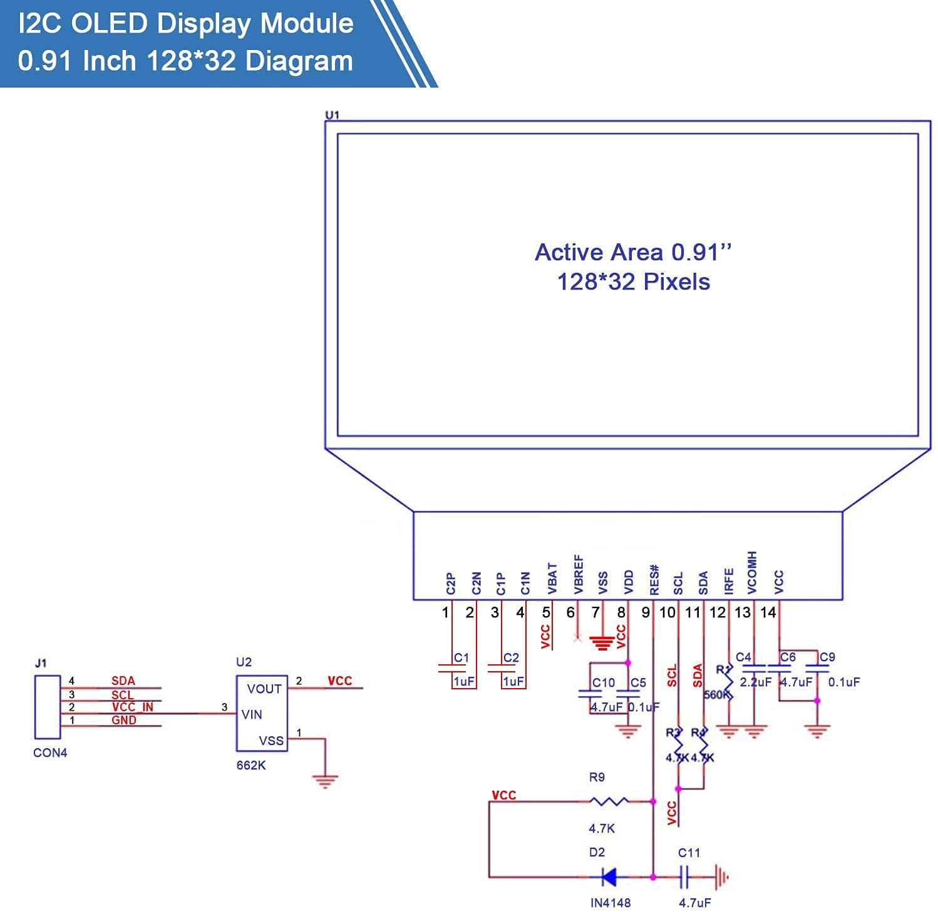
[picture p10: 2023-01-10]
doc/components/oled_128x32/61LiyJZ4GIL._SL1498_.jpg

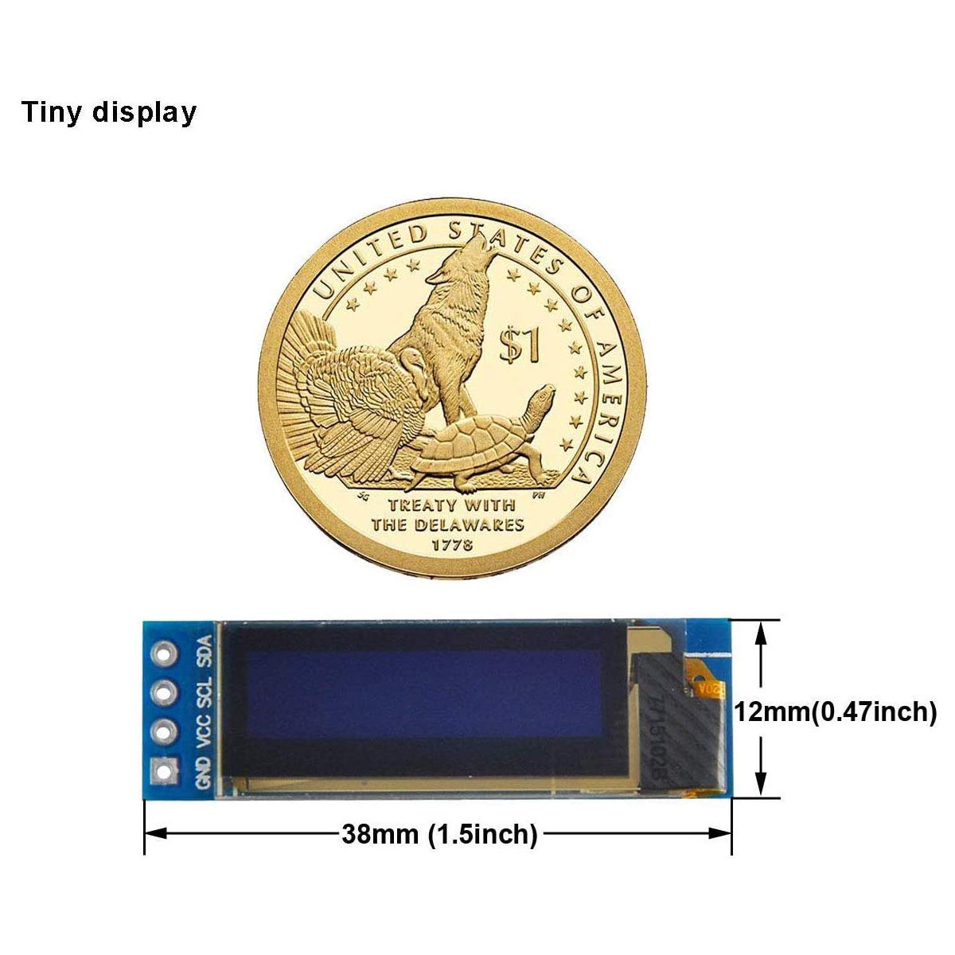
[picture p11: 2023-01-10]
doc/components/oled_128x32/6191e6AJvGL._SL1200_.jpg

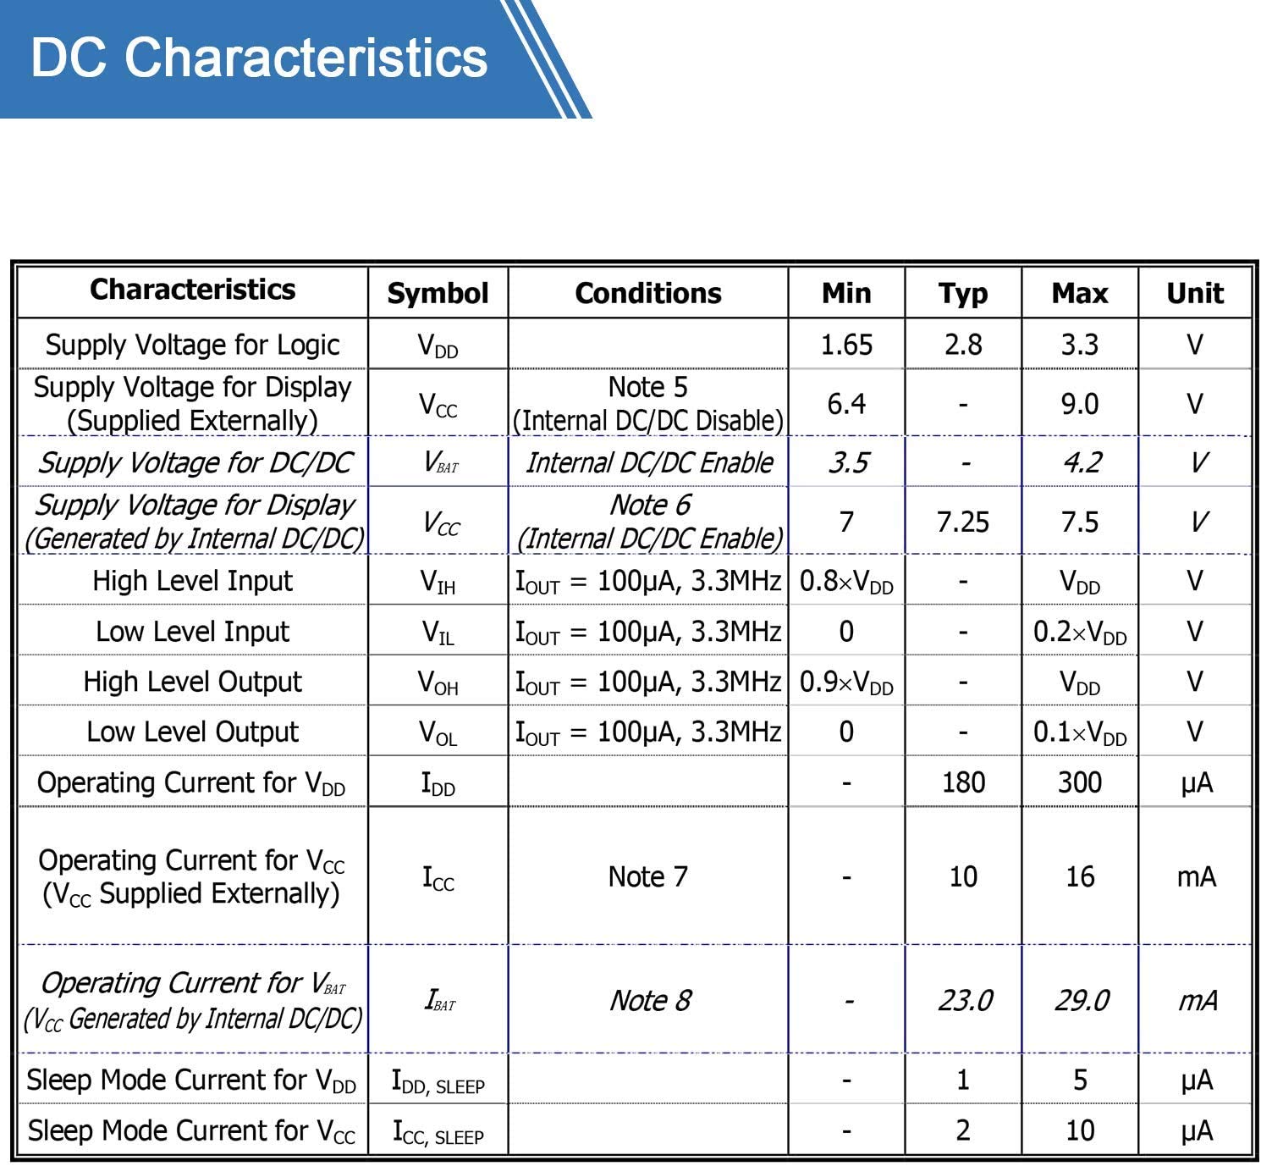
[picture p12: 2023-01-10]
doc/components/oled_128x32/71TdGEpA7nL._SL1490_.jpg

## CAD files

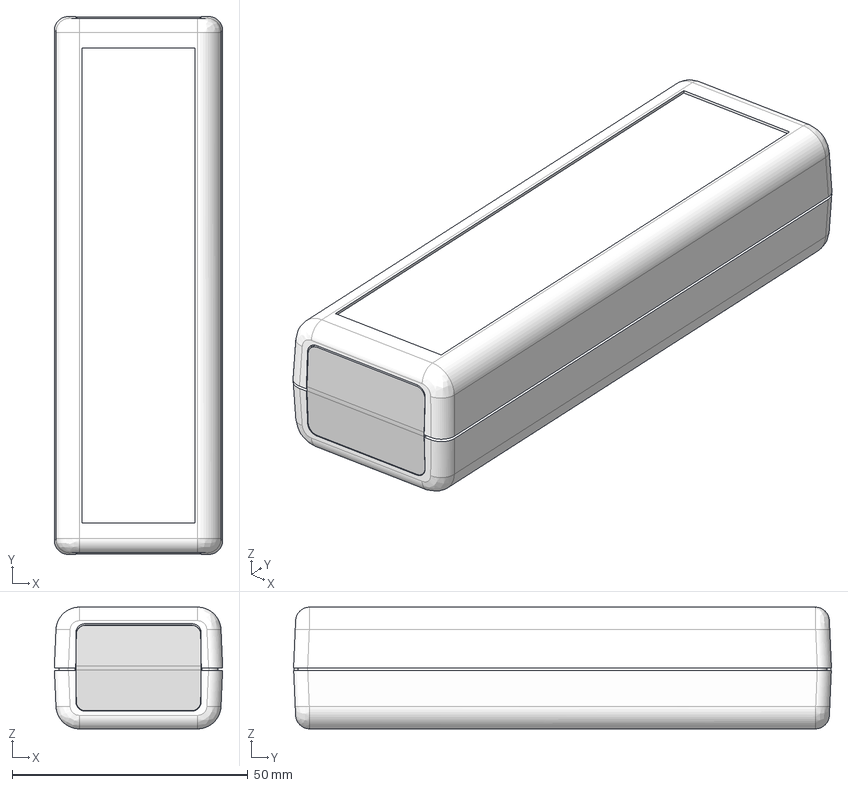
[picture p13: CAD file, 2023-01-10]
freecad/1593DBK/1593D.stp
35.7 x 114.0 x 25.8 mm
1593D Bottom
1593D Top
1593D Endplate x 2
1593D Contoured Endplate x 2
1593D PCB

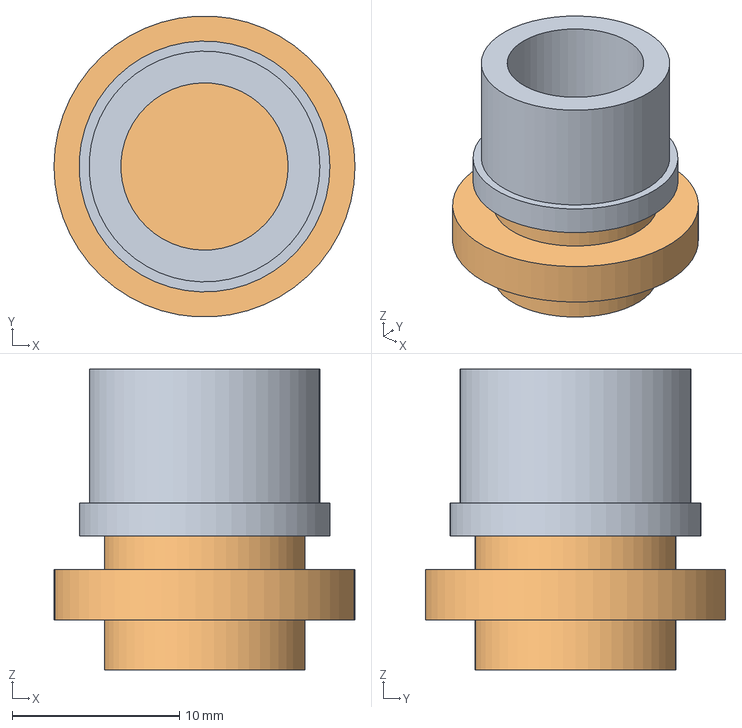
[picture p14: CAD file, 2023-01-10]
freecad/xs12.FCStd
18.0 x 18.0 x 18.0 mm

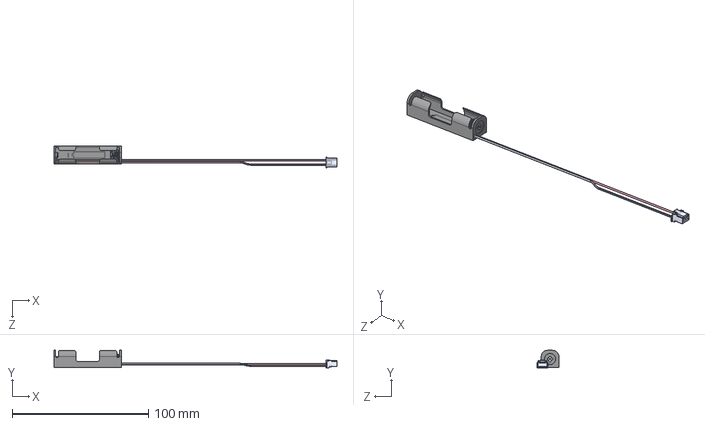
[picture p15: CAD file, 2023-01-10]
freecad/keystone-PN2467CN.step
207.7 x 12.9 x 16.1 mm

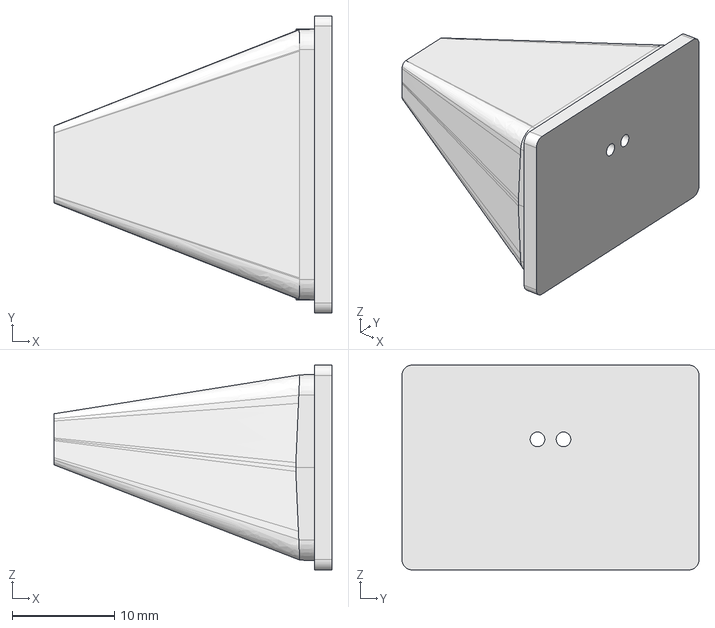
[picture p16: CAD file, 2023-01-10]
freecad/noseCone.STEP
27.1 x 29.0 x 20.0 mm

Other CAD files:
freecad/batterymeter_caseonly.FCStd
freecad/nose.FCStd
freecad/1593DBK/1593D.igs

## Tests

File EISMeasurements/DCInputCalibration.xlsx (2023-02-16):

DMM | rawv | reading | calc | error | factor | 10.047
0.5005 | 1664 | 0.5223 | 0.503605875 | 0.003105875 | offset | 60
1.002 | 3257 | 1.0224 | 1.003758094 | 0.00175809375
1.4985 | 4843 | 1.5202 | 1.501712531 | 0.00321253125
1.9999 | 6438 | 2.0209 | 2.002492688 | 0.0025926875
2.9978 | 9606 | 3.0154 | 2.997145688 | -0.0006543125
4.998 | 15968 | 5.0125 | 4.994614875 | -0.003385125
9.9977 | 31894 | 10.0117 | 9.994881188 | -0.0028188125
15.0021 | 47840 | 15.0173 | 15.00142688 | -0.000673125
20.001 | 63772 | 20.0184 | 20.003577 | 0.002577

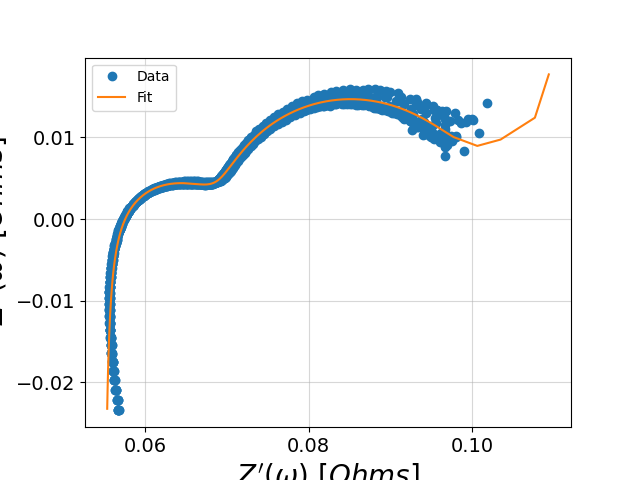
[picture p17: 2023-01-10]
EISMeasurements/impedancefit_all.png

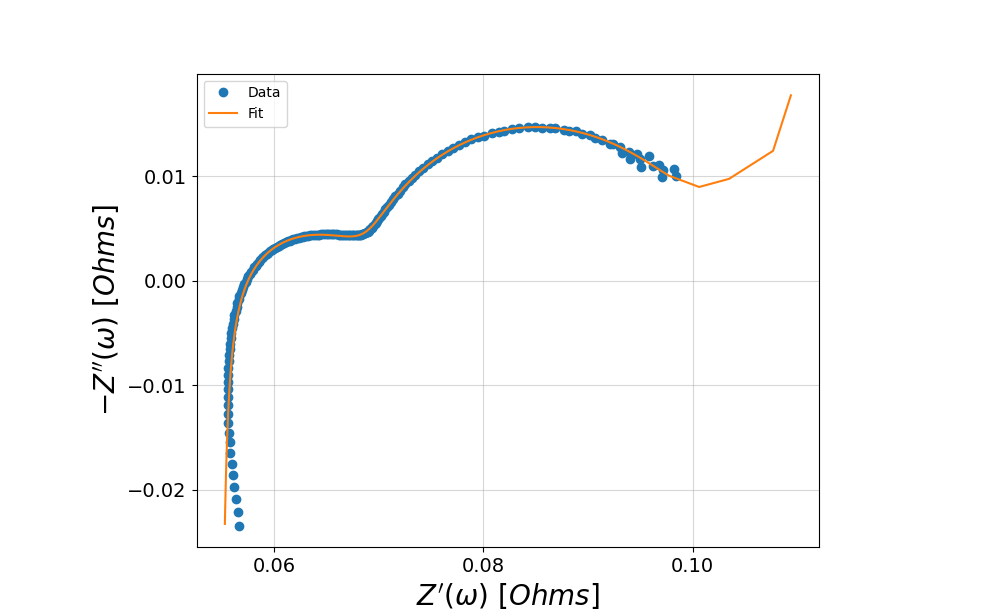
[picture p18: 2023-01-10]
EISMeasurements/impedancefit.png

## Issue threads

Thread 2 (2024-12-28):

Reverse engineering the yr1035, yr1035+ input?

nlroth, 2024-12-28:
Hi,
My yr1035+ recently became defective on the voltmeter function. It measures impedance but voltage shows a constant OL .
I noticed you have reversed the yr1030 input and was wondering if you went further than just what is shown in your schematic.
I found a clear photo of the yr1035 on a Russian forum with IC numbers intact:
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

I assume the additional opamp & potentiometers support the 0-100v range of the + version.

Any ideas on trouble shooting the voltage input circuitry would be appreciated.

Thanks
Larry

hb020, 2024-12-28:
Sorry, not done much more reverse engineering. But am willing to help out with measurements if you want. Mine is also a yr1035+, with all part numbers scraped off. It is likely that for V measurement, the path is like follows:
* high impedance voltage divider
* then the switches (HC4052 or HC4053) and the opamps (TL062 or TP5552 much more likely than LM324) (don't know what order)
* ADC

nlroth, 2024-12-28:
Ok, thank you.
Yes, the A/D is the small sot23-6 with CAM2 designation (u20) and appears to be an MCP3421.There are also several versions of the yr1035+ PCB with lasered IC tops:-2 white relays and 5 pots (w1-5)-2 MOSFETs soldered to board and 5 pots (w1-5)-2 MOSFETs mounted on daughter boards only 4 pots (w1-4) (my yr1035+)
The more info and images that are available, the easier it is to reverse engineer.
Since the yr1035+ has pots on the input ranges, recalibration may be possible.There are 3 new ICs on the input: the hi impedance buffer (TL062?), a regulator (sot23-5) & IC 15, most likely an hc4052 for switching 4 voltage ranges.
This is looking good so far. Let me know if you'd like me to upload images of the 3 PCBs above.
... Larry 

hb020, 2024-12-28:
The picture above is exactly like my yr1035+ (but I have Nichicon input caps), it has no pots. Indeed, pictures might be interesting, although eevblog would be a better place for that.

nlroth, 2024-12-28:
The 1st photo I uploaded is not the '+' version - it is from a yr1035.Here is a section of the yr1035+ with areas circled that are not on the yr1035:

hb020, 2024-12-29:
would like to see the outside of what you call the + version. What I frequently see is this: (all from https://budgetlightforum.com/t/test-review-of-internal-resistance-tester-yr1035/50875)

yr1035:
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

yr1035+:
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

Totally different layout. I have the latter.

nlroth, 2024-12-29:
This is very interesting. 
The yr1030 sold by various vendors on AliEx are packaged in the same housing as the yr1035 and use a USB -A type connector located at the top-end of the device for the probe connector.
There appears to be several dozen variations of PCB layouts and circuit designs of all these devices.As I was mainly interested in my '35+ unit, I concentrated on the devices with the newer housings and searched for PCB images on AliEx buyer reviews and other user forums.Purchasers of the yr1035 non-plus units who posted pics, showed the 1st image I posted here previously and those with the plus version posted pics showing the added input circuitry I highlighted.There is a lot of innovation going on in China with all the 'copying'.
Your documentation is the only one I found with a partial input schematic, which is a great start. The only part left to ID is the new 8pin chip.
I will be borrowing a friend's unit to compare voltage measurements. Hopefully, it will be physically similar to mine but at this point, who knows...
Cheers Larry

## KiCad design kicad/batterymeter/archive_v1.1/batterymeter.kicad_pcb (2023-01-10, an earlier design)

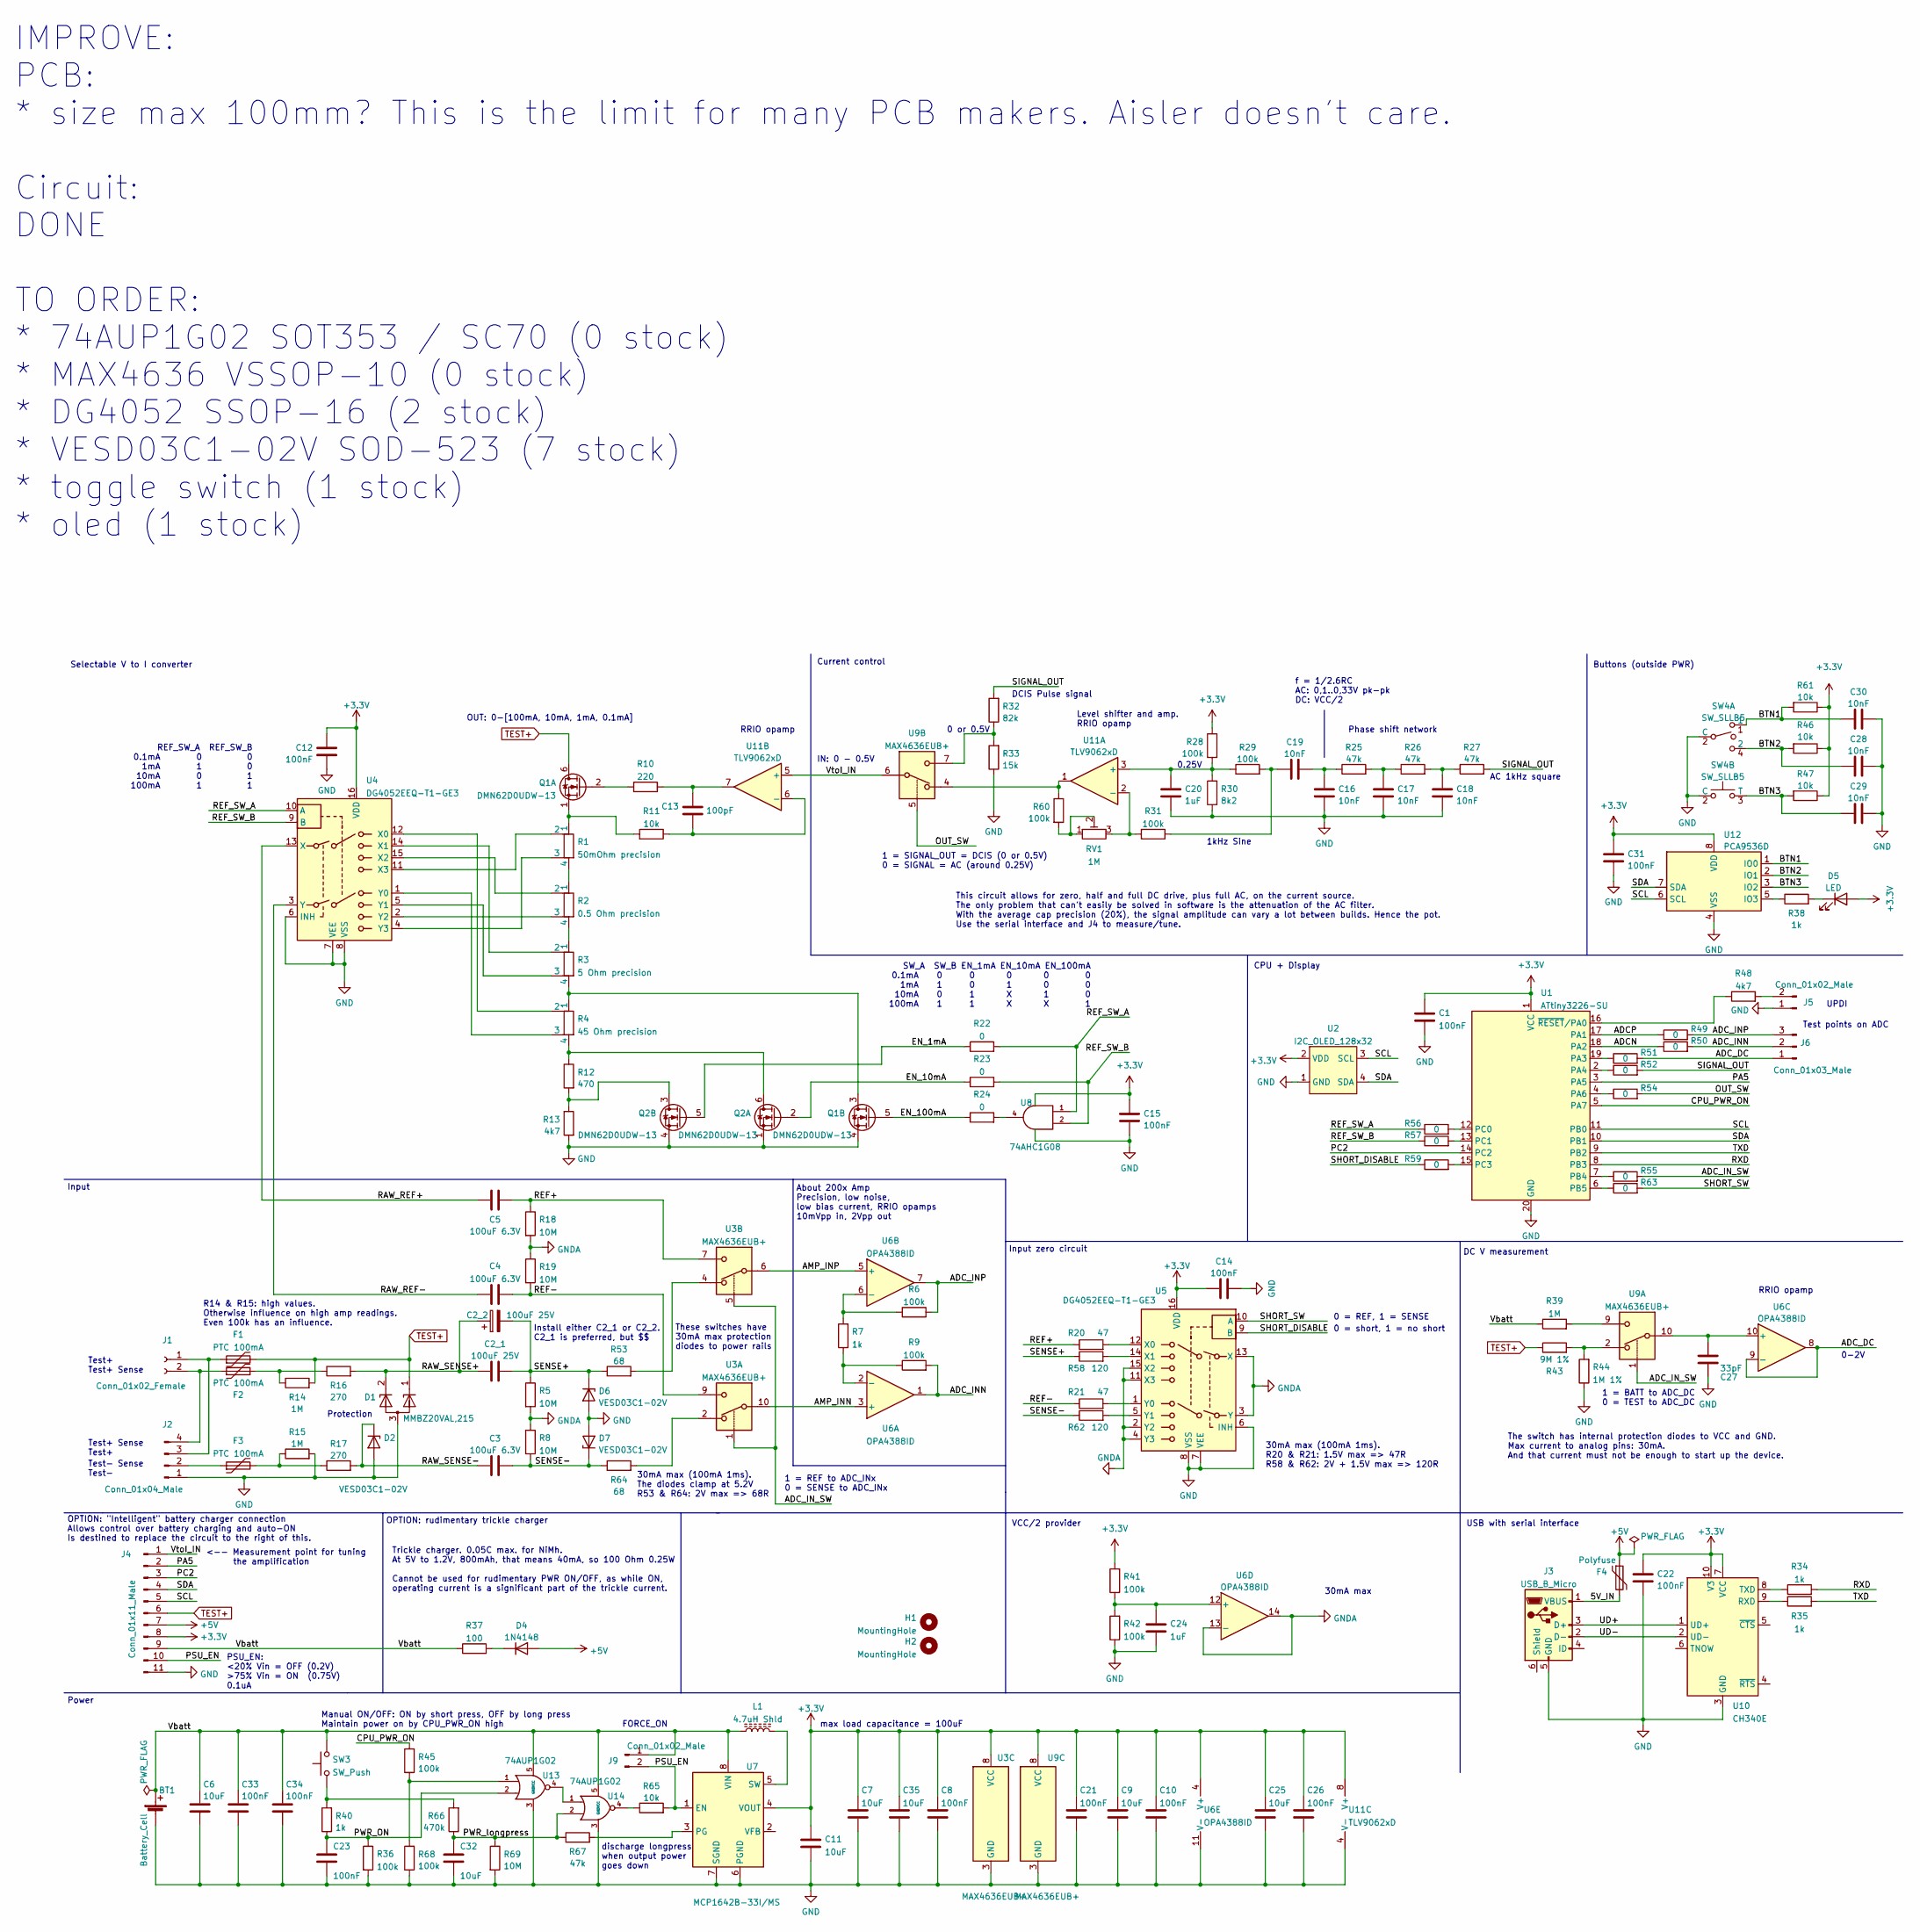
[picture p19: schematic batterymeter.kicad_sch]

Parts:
BT1: Battery_Cell; BatteryHolder_Keystone_2466_1xAAA
C1, C8, C10, C12, C14, C15, C21, C22, C23, C26, C31, C33, C34: 100nF; C_0805_2012Metric_Pad1.18x1.45mm_HandSolder
C2_1: 100uF 25V; KCM55WC71E107MH13
C2_2: 100uF 25V; CP_Elec_6.3x7.7
C3, C4, C5: 100uF 6.3V; C_1206_3216Metric_Pad1.33x1.80mm_HandSolder
C6, C7, C9, C11, C25, C32, C35: 10uF; C_0805_2012Metric_Pad1.18x1.45mm_HandSolder
C13: 100pF; C_0805_2012Metric_Pad1.18x1.45mm_HandSolder
C16, C17, C18, C19, C28, C29, C30: 10nF; C_0805_2012Metric_Pad1.18x1.45mm_HandSolder
C20, C24: 1uF; C_0805_2012Metric_Pad1.18x1.45mm_HandSolder
C27: 33pF; C_0805_2012Metric_Pad1.18x1.45mm_HandSolder
D1: MMBZ20VAL,215; SOT-23
D2, D6, D7: VESD03C1-02V; D_SOD-523
D4: 1N4148; D_SOD-123
D5: LED; LED_1206_3216Metric_Pad1.42x1.75mm_HandSolder
F1, F2, F3: PTC 100mA; Fuse_1206_3216Metric_Pad1.42x1.75mm_HandSolder
F4: Polyfuse; Fuse_1206_3216Metric_Pad1.42x1.75mm_HandSolder
H1, H2: MountingHole; MountingHole_3.2mm_M3_ISO14580
J1: Conn_01x02_Female; PinSocket_1x02_P2.54mm_Horizontal
J2: Conn_01x04_Male; JST_XH_B4B-XH-A_1x04_P2.50mm_Vertical
J3: USB_B_Micro; USB_Micro-B_mine
J4: Conn_01x11_Male; PinHeader_1x11_P2.54mm_Vertical
J5, J9: Conn_01x02_Male; PinHeader_1x02_P2.54mm_Vertical
J6: Conn_01x03_Male; PinHeader_1x03_P2.54mm_Vertical
L1: 4.7uH Shld; L_Coilcraft_LPS4018
Q1, Q2: DMN62D0UDW-13; SOT-363_SC-70-6
R1: 50mOhm precision; R_Shunt_Ohmite_LVK12_ALT
R2: 0.5 Ohm precision; R_1206_3216Metric_4Wire
R3: 5 Ohm precision; R_1206_3216Metric_4Wire
R4: 45 Ohm precision; R_1206_3216Metric_4Wire
R5, R8, R18, R19, R69: 10M; R_0805_2012Metric_Pad1.20x1.40mm_HandSolder
R6, R9, R28, R29, R31, R36, R41, R42, R45, R60, R68: 100k; R_0805_2012Metric_Pad1.20x1.40mm_HandSolder
R7, R34, R35, R38, R40: 1k; R_0805_2012Metric_Pad1.20x1.40mm_HandSolder
R10: 220; R_0805_2012Metric_Pad1.20x1.40mm_HandSolder
R11, R46, R47, R61, R65: 10k; R_0805_2012Metric_Pad1.20x1.40mm_HandSolder
R12: 470; R_0805_2012Metric_Pad1.20x1.40mm_HandSolder
R13, R48: 4k7; R_0805_2012Metric_Pad1.20x1.40mm_HandSolder
R14, R15, R39: 1M; R_0805_2012Metric_Pad1.20x1.40mm_HandSolder
R16, R17: 270; R_0805_2012Metric_Pad1.20x1.40mm_HandSolder
R20, R21: 47; R_0805_2012Metric_Pad1.20x1.40mm_HandSolder
R22, R23, R24, R49, R50, R51, R52, R54, R55, R56, R57, R59, R63: 0; R_0805_2012Metric_Pad1.20x1.40mm_HandSolder
R25, R26, R27, R67: 47k; R_0805_2012Metric_Pad1.20x1.40mm_HandSolder
R30: 8k2; R_0805_2012Metric_Pad1.20x1.40mm_HandSolder
R32: 82k; R_0805_2012Metric_Pad1.20x1.40mm_HandSolder
R33: 15k; R_0805_2012Metric_Pad1.20x1.40mm_HandSolder
R37: 100; R_1206_3216Metric_Pad1.30x1.75mm_HandSolder
R43: 9M 1%; R_0805_2012Metric_Pad1.20x1.40mm_HandSolder
R44: 1M 1%; R_0805_2012Metric_Pad1.20x1.40mm_HandSolder
R53, R64: 68; R_0805_2012Metric_Pad1.20x1.40mm_HandSolder
R58, R62: 120; R_0805_2012Metric_Pad1.20x1.40mm_HandSolder
R66: 470k; R_0805_2012Metric_Pad1.20x1.40mm_HandSolder
RV1: 1M; Potentiometer_Bourns_3266Y_Vertical
SW3: SW_Push; SW_Tactile_SPST_Angled_PTS645Vx83-2LFS
SW4: SW_SLLB5; SW_SLLB510100
U1: ATtiny3226-SU; SOIC-20W_7.5x12.8mm_P1.27mm
U2: I2C_OLED_128x32
U3, U9: MAX4636EUB+; VSSOP-10_3x3mm_P0.5mm
U4, U5: DG4052EEQ-T1-GE3; TSSOP-16_4.4x5mm_P0.65mm
U6: OPA4388ID; SOIC-14_3.9x8.7mm_P1.27mm
U7: MCP1642B-33I/MS; MSOP-8_3x3mm_P0.65mm
U8: 74AHC1G08; SOT-23-5_HandSoldering
U10: CH340E; MSOP-10_3x3mm_P0.5mm
U11: TLV9062xD; VSSOP-8_3.0x3.0mm_P0.65mm
U12: PCA9536D; SOIC-8_3.9x4.9mm_P1.27mm
U13, U14: 74AUP1G02; SOT-353_SC-70-5_Handsoldering

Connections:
+3V3: C1.1, C7.1, C8.1, C9.1, C10.1, C11.1, C12.1, C14.1, C15.1, C21.1, C22.1, C25.1, C26.1, C31.1, C35.1, D5.2 (A), J4.8, R28.2, R41.2, R46.1, R47.1, R61.1, U1.1 (VCC), U2.2 (VDD), U3.8 (VCC), U4.16 (VDD), U5.16 (VDD), U6.4 (V+), U7.4 (VOUT), U8.5 (VCC), U9.8 (VCC), U10.7 (VCC), U10.10 (V3), U11.8 (V+), U12.8 (VDD)
+5V: D4.2 (A), F4.1, J4.7
/5V_IN: F4.2, J3.1 (VBUS)
/ADCN: R50.1, U1.18 (PA2)
/ADCP: R49.1, U1.17 (PA1)
/ADC_DC: J6.1, R51.2, U6.8, U6.9 (-)
/ADC_INN: J6.2, R9.2, R50.2, U6.1
/ADC_INP: J6.3, R6.2, R49.2, U6.7
/ADC_IN_SW: R55.2, U3.1, U3.5, U9.1
/AMP_INN: U3.10, U6.3 (+)
/AMP_INP: U3.6, U6.5 (+)
/BTN1: C30.1, R61.2, SW4.1, U12.1 (IO0)
/BTN2: C28.1, R46.2, SW4.4 (2), U12.2 (IO1)
/BTN3: C29.1, R47.2, SW4.3 (T), U12.3 (IO2)
/CPU_PWR_ON: R45.2, U1.5 (PA7)
/EN_1mA: Q2.5 (G), R22.1
/EN_10mA: Q2.2 (G), R23.1
/EN_100mA: Q1.5 (G), R24.1
/OUT_SW: R54.2, U9.5
/PA5: J4.2, U1.3 (PA5)
/PC2: J4.3, U1.14 (PC2)
/PSU_EN: J4.10, J9.2, R65.2, U7.1 (EN)
/PWR_ON: C23.1, R36.1, R40.1, U13.2
/PWR_longpress: C32.1, R66.1, R67.1, R69.1, U14.2
/RAW_REF+: C5.1, U4.13 (X)
/RAW_REF-: C4.1, U4.3 (Y)
/RAW_SENSE+: C2_1.1, C2_2.1, D1.2 (K), R16.2
/RAW_SENSE-: C3.1, D2.1 (K), R17.2
/REF+: C5.2, R18.1, R20.1, U3.7
/REF-: C4.2, R19.2, R21.1, U3.9
/REF_SW_A: R22.2, R56.1, U4.10 (A), U8.1
/REF_SW_B: R23.2, R57.1, U4.9 (B), U8.2
/RXD: R34.2, U1.8 (PB3)
/SCL: J4.5, U1.11 (PB0), U2.3 (SCL), U12.6 (SCL)
/SDA: J4.4, U1.10 (PB1), U2.4 (SDA), U12.7 (SDA)
/SENSE+: C2_1.2, C2_2.2, D6.1 (K), R5.1, R53.1, R58.1
/SENSE-: C3.2, D7.1 (K), R8.2, R62.1, R64.1
/SHORT_DISABLE: R59.1, U5.9 (B)
/SHORT_SW: R63.2, U5.10 (A)
/SIGNAL_OUT: R27.2, R32.2, R52.2
/TXD: R35.2, U1.9 (PB2)
/UD+: J3.3 (D+), U10.1 (UD+)
/UD-: J3.2 (D-), U10.2 (UD-)
/Vbatt: BT1.1 (+), C6.1, C33.1, C34.1, J4.9, J9.1, L1.1, R37.1, R39.1, SW3.2, U7.8 (VIN), U13.5 (VCC), U14.5 (VCC)
/VtoI_IN: J4.1, U9.6, U11.5 (+)
GND: BT1.2 (-), C1.2, C6.2, C7.2, C8.2, C9.2, C10.2, C11.2, C12.2, C14.2, C15.2, C16.2, C17.2, C18.2, C20.1, C21.2, C22.2, C23.2, C24.2, C25.2, C26.2, C27.2, C28.2, C29.2, C30.2, C31.2, C32.2, C33.2, C34.2, C35.2, D1.3 (A), D2.2 (A), D6.2 (A), D7.2 (A), J2.1, J3.5 (GND), J4.11, J5.1, Q1.4 (S), Q2.1 (S), Q2.4 (S), R13.2, R15.2, R30.1, R33.1, R36.2, R42.1, R44.1, R68.1, R69.2, SW4.2 (C), U1.20 (GND), U2.1 (GND), U3.3 (GND), U4.6 (INH), U4.7 (VEE), U4.8 (VSS), U5.6 (INH), U5.7 (VEE), U5.8 (VSS), U6.11 (V-), U7.6 (PGND), U7.7 (SGND), U8.3 (GND), U9.3 (GND), U10.3 (GND), U11.4 (V-), U12.4 (VSS), U13.3 (GND), U14.3 (GND)
GNDA: R5.2, R8.1, R18.2, R19.1, U5.2 (Y2), U5.3 (Y), U5.4 (Y3), U5.11 (X3), U5.13 (X), U5.15 (X2), U6.13 (-), U6.14
unnamed: C13.1, R11.1, U11.6 (-)
unnamed: C13.2, R10.1, U11.7
unnamed: C16.1, C19.2, R25.1
unnamed: C17.1, R25.2, R26.1
unnamed: C18.1, R26.2, R27.1
unnamed: C19.1, R29.2, R31.1
unnamed: C20.2, R28.1, R29.1, R30.2, U11.3 (+)
unnamed: C24.1, R41.1, R42.2, U6.12 (+)
unnamed: C27.1, U6.10 (+), U9.10
unnamed: D4.1 (K), R37.2
unnamed: D5.1 (K), R38.2
unnamed: F1.1, J1.1, J2.3
unnamed: F2.1, J1.2, J2.4
unnamed: F2.2, R14.1, R16.1
unnamed: F3.1, J2.2
unnamed: F3.2, R15.1, R17.1
unnamed: J5.2, R48.2
unnamed: L1.2, U7.5 (SW)
unnamed: Q1.1 (S), R1.1, R11.2
unnamed: Q1.2 (G), R10.2
unnamed: Q1.3 (D), R3.4, R4.1
unnamed: Q2.3 (D), R12.2, R13.1
unnamed: Q2.6 (D), R4.4, R12.1
unnamed: R1.2, U4.11 (X3)
unnamed: R1.3, U4.4 (Y3)
unnamed: R1.4, R2.1
unnamed: R2.2, U4.15 (X2)
unnamed: R2.3, U4.2 (Y2)
unnamed: R2.4, R3.1
unnamed: R3.2, U4.14 (X1)
unnamed: R3.3, U4.5 (Y1)
unnamed: R4.2, U4.12 (X0)
unnamed: R4.3, U4.1 (Y0)
unnamed: R6.1, R7.2, U6.6 (-)
unnamed: R7.1, R9.1, U6.2 (-)
unnamed: R20.2, U5.12 (X0)
unnamed: R21.2, U5.1 (Y0)
unnamed: R24.2, U8.4
unnamed: R31.2, RV1.3, U11.2 (-)
unnamed: R32.1, R33.2, U9.7
unnamed: R34.1, U10.8 (TXD)
unnamed: R35.1, U10.9 (RXD)
unnamed: R38.1, U12.5 (IO3)
unnamed: R39.2, U9.9
unnamed: R40.2, R66.2, SW3.1
unnamed: R43.2, R44.2, U9.2
unnamed: R45.1, R68.2, U13.1
unnamed: R48.1, U1.16 (~RESET/PA0)
unnamed: R51.1, U1.19 (PA3)
unnamed: R52.1, U1.2 (PA4)
unnamed: R53.2, U3.4
unnamed: R54.1, U1.4 (PA6)
unnamed: R55.1, U1.7 (PB4)
unnamed: R56.2, U1.12 (PC0)
unnamed: R57.2, U1.13 (PC1)
unnamed: R58.2, U5.14 (X1)
unnamed: R59.2, U1.15 (PC3)
unnamed: R60.1, U9.4, U11.1
unnamed: R60.2, RV1.1, RV1.2
unnamed: R62.2, U5.5 (Y1)
unnamed: R63.1, U1.6 (PB5)
unnamed: R64.2, U3.2
unnamed: R65.1, U14.4
unnamed: R67.2, U7.3 (PG)
unnamed: U13.4, U14.1
TEST+: D1.1 (K), F1.2, J4.6, Q1.6 (D), R14.2, R43.1

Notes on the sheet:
Power
30mA max (100mA 1ms). R20 & R21: 1.5V max => 47R R58 & R62: 2V + 1.5V max => 120R
0-2V
30mA max
0 = REF, 1 = SENSE
Protection
The switch has internal protection diodes to VCC and GND. Max current to analog pins: 30mA. And that current must not be enough to start up the device.
Test+ Test+ Sense
1 = REF to ADC_INx 0 = SENSE to ADC_INx
1 = BATT to ADC_DC 0 = TEST to ADC_DC
R14 & R15: high values. Otherwise influence on high amp readings. Even 100k has an influence.
0 or 0.5V
IMPROVE: PCB: * size max 100mm? This is the limit for many PCB makers. Aisler doesn't care. Circuit: DONE TO ORDER: * 74AUP1G02 SOT353 / SC70 (0 stock) * MAX4636 VSSOP-10 (0 stock) * DG4052 SSOP-16 (2 stock) * VESD03C1-02V SOD-523 (7 stock) * toggle switch (1 stock) * oled (1 stock)
Manual ON/OFF: ON by short press, OFF by long press Maintain power on by CPU_PWR_ON high
Buttons (outside PWR)
About 200x Amp Precision, low noise, low bias current, RRIO opamps 10mVpp in, 2Vpp out
OPTION: rudimentary trickle charger
0.25V
This circuit allows for zero, half and full DC drive, plus full AC, on the current source. The only problem that can't easily be solved in software is the attenuation of the AC filter. With the average cap precision (20%), the signal amplitude can vary a lot between builds. Hence the pot. Use the s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
DC V measurement
OPTION: "Intelligent" battery charger connection Allows control over battery charging and auto-ON Is destined to replace the circuit to the right of this.
Selectable V to I converter
Test+ Sense Test+
1kHz Sine
30mA max (100mA 1ms). The diodes clamp at 5.2V R53 & R64: 2V max => 68R
Test points on ADC
DCIS Pulse signal
max load capacitance = 100uF
RRIO opamp
OUT: 0-[100mA, 10mA, 1mA, 0.1mA]
AC 1kHz square
discharge longpress when output power goes down
Phase shift network
Install either C2_1 or C2_2. C2_1 is preferred, but $$
USB with serial interface
VCC/2 provider
PSU_EN: <20% Vin = OFF (0.2V) >75% Vin = ON (0.75V) 0.1uA
CPU + Display
Test- Sense Test-
REF_SW_A REF_SW_B 0.1mA 0 0 1mA 1 0 10mA 0 1 100mA 1 1

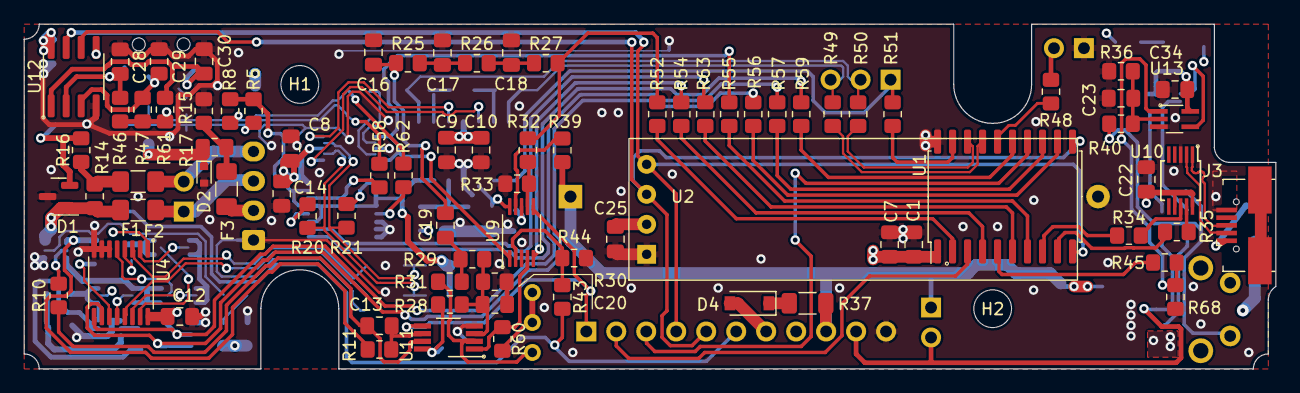
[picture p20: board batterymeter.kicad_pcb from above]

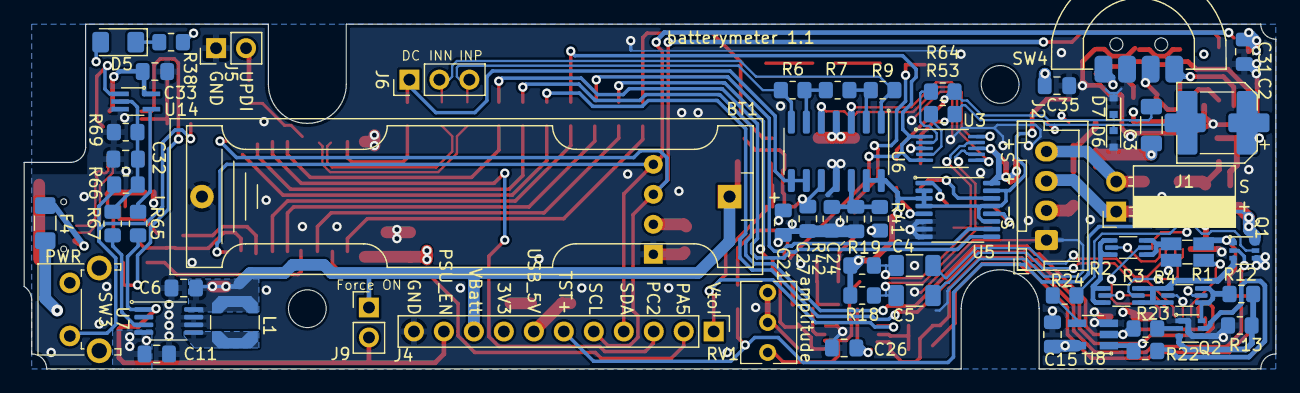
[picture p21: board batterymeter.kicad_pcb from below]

Board: 4 copper layers, 106.0 x 29.2 mm, 145 parts (62 on the bottom side), 113 nets.

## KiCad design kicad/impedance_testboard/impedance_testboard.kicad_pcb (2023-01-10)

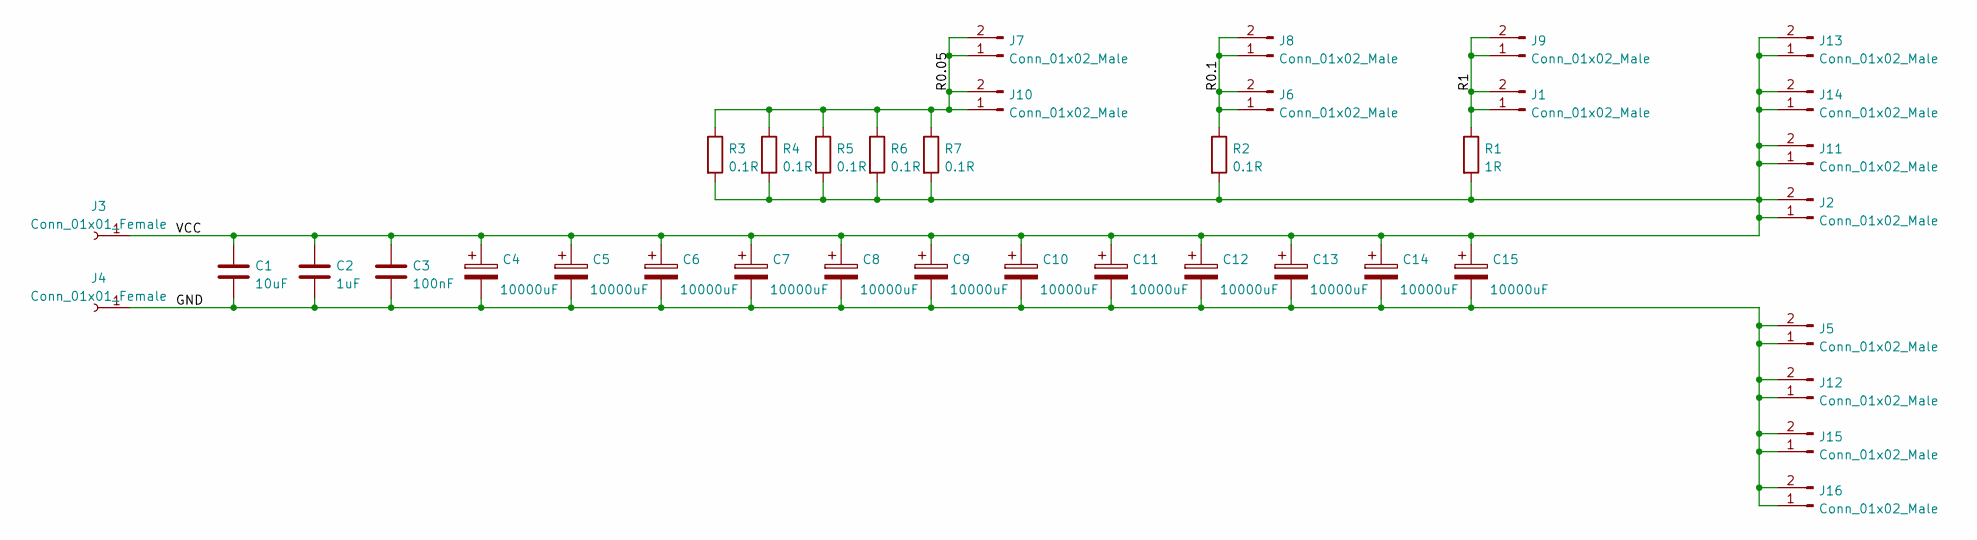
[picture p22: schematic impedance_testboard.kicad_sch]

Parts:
C1: 10uF; C_1206_3216Metric_Pad1.33x1.80mm_HandSolder
C2: 1uF; C_1206_3216Metric_Pad1.33x1.80mm_HandSolder
C3: 100nF; C_1206_3216Metric_Pad1.33x1.80mm_HandSolder
C4, C5, C6, C7, C8, C9, C10, C11, C12, C13, C14, C15: 10000uF; C_Radial_D18.0mm_H35.5mm_P7.50mm
J1, J2, J5, J6, J7, J8, J9, J10, J11, J12, J13, J14, J15, J16: Conn_01x02_Male; PinHeader_1x02_P2.54mm_Vertical
J3, J4: Conn_01x01_Female; PinHeader_1x01_P2.54mm_Horizontal
R1: 1R; R_1206_3216Metric_Pad1.30x1.75mm_HandSolder
R2, R3, R4, R5, R6, R7: 0.1R; R_1206_3216Metric_Pad1.30x1.75mm_HandSolder

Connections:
/GND: C1.2, C2.2, C3.2, C4.2, C5.2, C6.2, C7.2, C8.2, C9.2, C10.2, C11.2, C12.2, C13.2, C14.2, C15.2, J4.1, J5.1, J5.2, J12.1, J12.2, J15.1, J15.2, J16.1, J16.2
/R0.1: J6.1, J6.2, J8.1, J8.2, R2.1
/R0.05: J7.1, J7.2, J10.1, J10.2, R3.1, R4.1, R5.1, R6.1, R7.1
/R1: J1.1, J1.2, J9.1, J9.2, R1.1
/VCC: C1.1, C2.1, C3.1, C4.1, C5.1, C6.1, C7.1, C8.1, C9.1, C10.1, C11.1, C12.1, C13.1, C14.1, C15.1, J2.1, J2.2, J3.1, J11.1, J11.2, J13.1, J13.2, J14.1, J14.2, R1.2, R2.2, R3.2, R4.2, R5.2, R6.2, R7.2

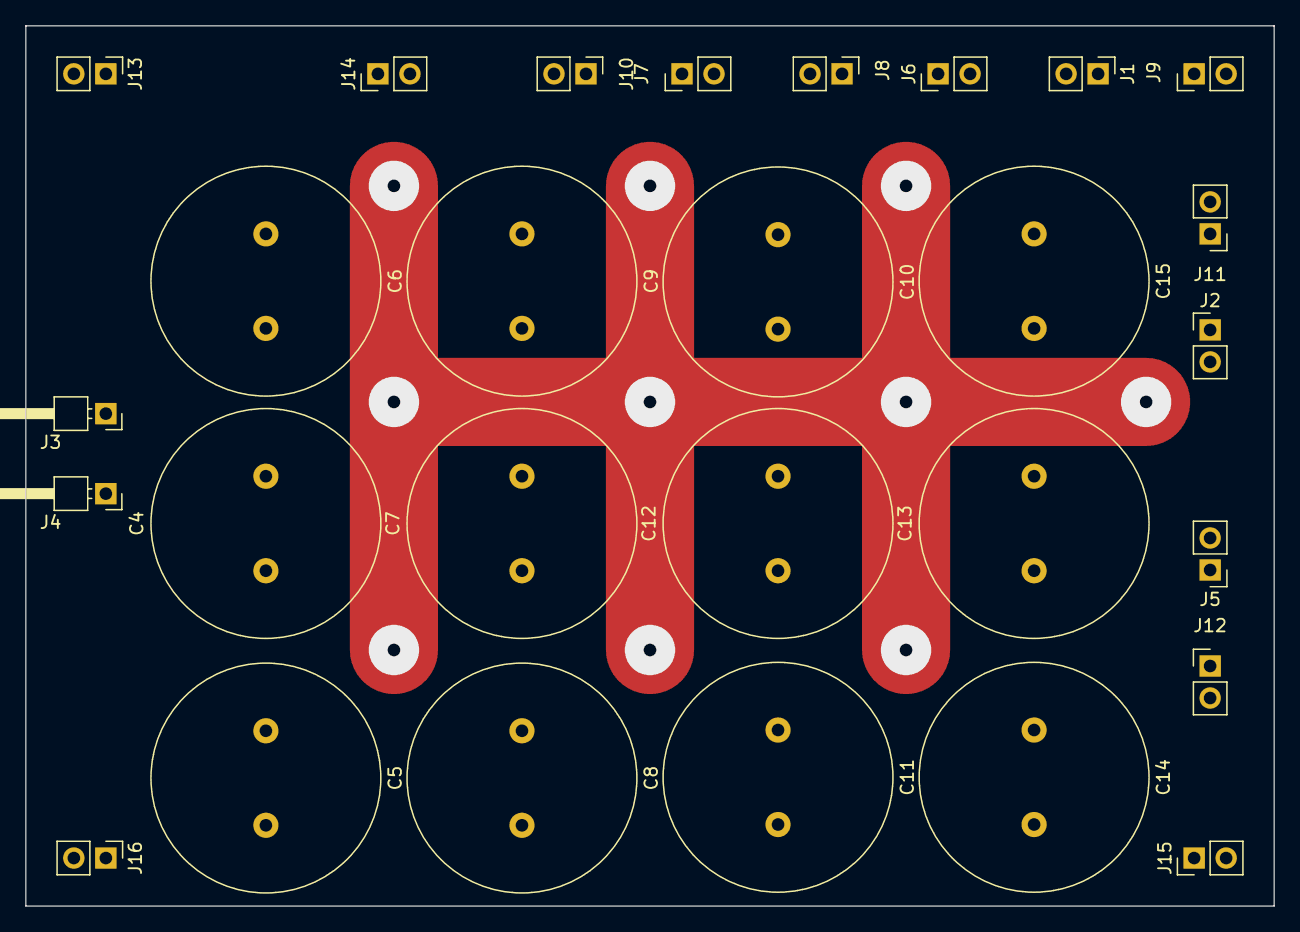
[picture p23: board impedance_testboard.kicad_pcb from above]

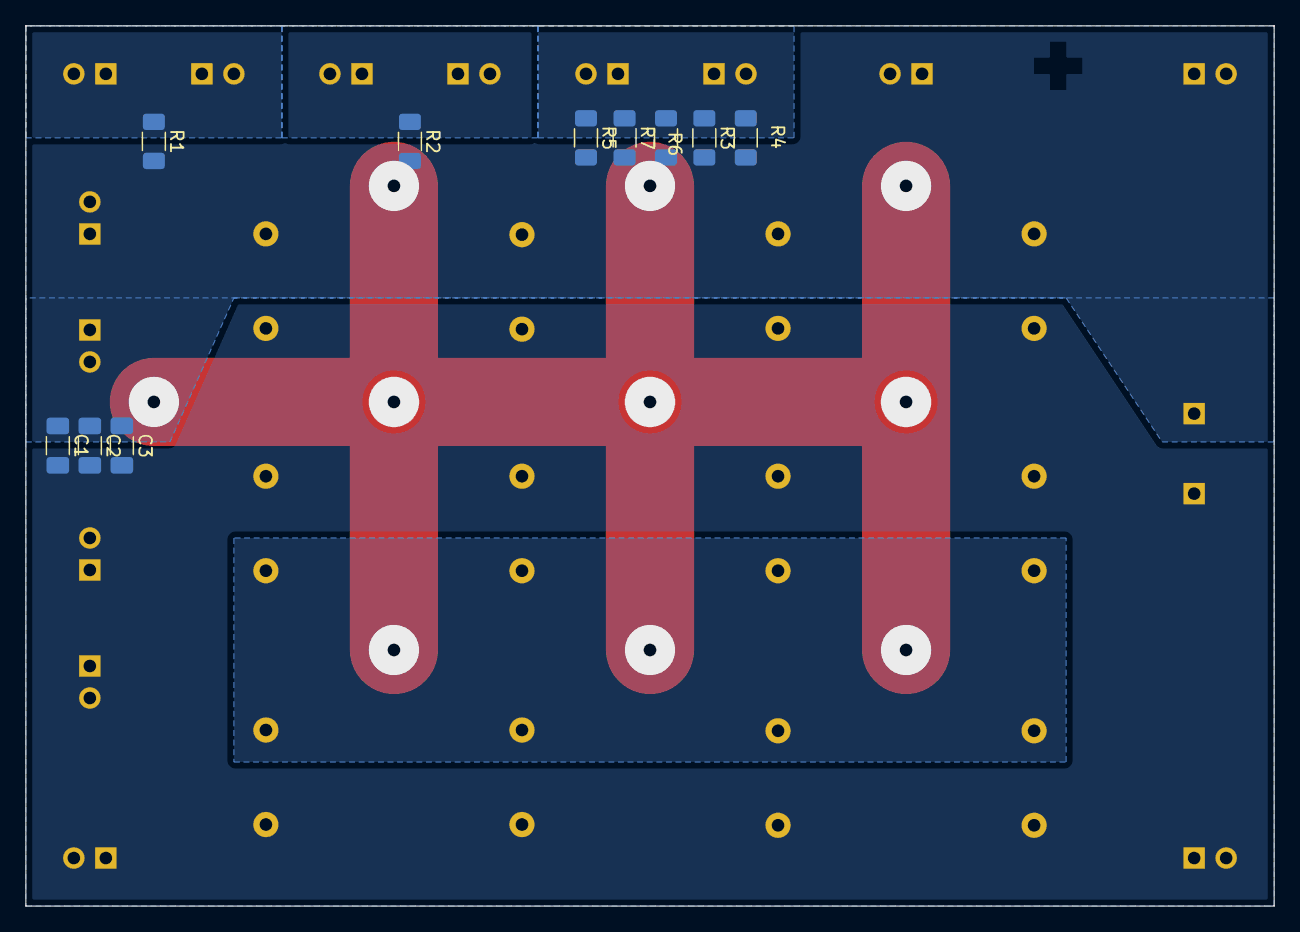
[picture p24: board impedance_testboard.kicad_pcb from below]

Board: 2 copper layers, 99.1 x 69.8 mm, 38 parts (10 on the bottom side), 5 nets.

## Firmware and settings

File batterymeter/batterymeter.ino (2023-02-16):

// ******* TEST settings ********
//#define TEST_BLINKY
//#define TEST_TYPES
//#define TEST_OLED

//#define DEBUG_MSG

// The serial interface. SCPI or more debug/dev-oriented
// ifdef COMMANDS_DEBUG: debug/dev commands enabled
// ifndef COMMANDS_DEBUG: SCPI commands enabled
//#define COMMANDS_DEBUG

// About PROGMEM: the compiler I use does not need PROGMEM, so I removed it on most places where you'd normally expect it.
// const declarations go to flash storage, but do not need memory mapping.

// TODO: look at TODOs below
// TODO allow key press interrupt the readings
// TODO show busy

// The different HW models
#define HW_V1_0 0
#define HW_V1_1 1

// what HW version this is for
#define HW_VERSION_ID HW_V1_1

#if HW_VERSION_ID == HW_V1_0
#define BODGE_REF_SW
#define BOARDHW_VERSION "1.0 with bodge"
#endif

#if HW_VERSION_ID == HW_V1_1
#define HW_VERSION "1.1"
#endif

#ifndef HW_VERSION
#error "You need to specify a HW version"
#endif

#ifdef TEST_BLINKY
#define NO_MAIN
#define NO_DISPLAY
#endif

#ifdef TEST_TYPES
#define NO_MAIN
#endif

#ifdef TEST_OLED
#define NO_MAIN
#endif

#define SW_VERSION "0.9d"

const char *AppName = "Batterymeter " SW_VERSION;

#include <Event.h>
#include <EEPROM.h>
#include <SparkFun_PCA9536_Arduino_Library.h>
#ifndef COMMANDS_DEBUG

// local version of SCPI lib, as I want to set the defines (and got some additions)
#define SCPI_MAX_TOKENS 30
#define SCPI_MAX_COMMANDS 25
#include "Vrekrer_scpi_parser_local.h"
#endif

#pragma region Arduino IDE PROGRAMMER settings
// ************************************************************************************************
// ******* Arduino IDE PROGRAMMER settings ********
// ************************************************************************************************

// This must be compiled from Arduino IDE for now, as
// * https://registry.platformio.org/platforms/platformio/atmelmegaavr is not supporting the 3226 yet (will be soon)
// * serialupdi in avrdude is not mainline yet (will be soon)

// Config:
// Board: MegaTinyCore Attiny 3226/....
// Chip: ATtiny3226
// Clock: 10MHz internal (because of 3.3V)
// Millis: TCB1 (I need TCA)
// printf(): full (haven't found a way to check that on compile time)
// Wire: Master or Slave
// Programmer: SerialUPDI SLOW

// !!!!!!! During programming, force the power on with the jumper, as the device otherwise switches off during programming !!!!!!

#ifndef ARDUINO_AVR_ATtiny3226
#error "Wrong CPU:  must be ATtiny3226"
#endif

#ifndef MILLIS_USE_TIMERB1
#error "I Need Timer B1 for millis"
#endif

#if F_CPU != 10000000L
#error "Wrong clock speed"
#endif
#pragma endregion

#pragma region Pinout and other hardware

// Types:
// float, double, int32_t, long = 4 bytes
// int64_t = 8 bytes
// int = 2 bytes

// ************************************************************************************************
// ******* Pinout ********
// ************************************************************************************************

// Pins 3226
//        func               | alt                         | debug use
//--------------------------+-----------------------------+----------------------
// 1  VDD                    |                             |
// 2  PA4 SIGNAL_OUT         | AIN4  !SS     WO4           |
// 3  PA5 free               | PA5 AIN5  VREFA   WO5 0.WO  | PA5 debug AC sampler
// 4  PA6 OUT_SW             | PA6 AIN6                    |
// 5  PA7 CPU_PWR_ON         | PA7 AIN7                    |
// 6  PB5 SHORT_SW           | PB5 AIN8          WO2'      |
// 7  PB4 ADC_IN_SW          | PB4 AIN9  !RESET' WO1'      |
// 8  RxD                    | PB3               WO0'      |
// 9  TxD                    | PB2               WO2       |
// 10 SDA                    | PB1 AIN10         WO1       |
// 11 SCL                    | PB0 AIN11         WO0       |
// 12 PC0 REF_SW_A           | PC0 AIN10 SCK'              |
// 13 PC1 REF_SW_B           | PC1 AIN13 MISO'             |
// 14 PC2 free               | PC2 AIN14 MOSI'             | EVOUTC debug AC sampler
// 15 PC3 SHORT_DISABLE      | PC3 AIN15 !SS'              |
// 16 UPDI                   | PA0 !RESET                  |
// 17 AIN1 ADC_INP           | PA1 MOSI                    |
// 18 AIN2 ADC_INN           | PA2 MISO                    |
// 19 AIN3 ADC_DC            | PA3 AIN3  SCK WO3  1.WO     |
// 20 GND                    |

// AIN[15:8] can not be used as negative ADC input for differential measurements.

// Signal levels:
// ADC_IN_SW : 1 = REF to ADC_INx, 0 = SENSE to ADC_INx, 1 = BATT to ADC_DC, 0 = TEST to ADC_DC
// SHORT_SW : 0 = REF, 1 = SENSE
// SHORT_DISABLE : 0 = short, 1 = no short
// BTN1 : 0 = pressed
// BTN2 : 0 = pressed
// REF_SW_A : see below
// REF_SW_B : see below
// OUT_SW : 1 = SIGNAL_OUT = DCIS, 0 = SIGNAL = AC
// CPU_PWR_ON : 1 = ON, 0 = OFF

// REF_SW_A = EN_1mA
// REF_SW_B = EN_10mA
// --- AND(REF_SW_A,REF_SW_B) = EN_100mA

//        SW_A  SW_B EN_1mA EN_10mA EN_100mA
// 100uA  0     0    0      0       0
//   1mA  1     0    1      0       0
//  10mA  0     1    x      1       0
// 100mA  1     1    x      x       1
//

#define SIGNAL_OUT PIN_PA4
//#define AC_SIGNAL_DEBUG_TRIGGERPIN_ON_PC2
//#define AC_SIGNAL_DEBUG_WAITPIN_ON_PA5

#define OUT_SW PIN_PA6
#define CPU_PWR_ON PIN_PA7
#define SHORT_SW PIN_PB5
#define ADC_IN_SW PIN_PB4

#define REF_SW_A PIN_PC0
#define REF_SW_B PIN_PC1

#ifdef BODGE_REF_SW
#ifdef AC_SIGNAL_DEBUG_TRIGGERPIN_ON_PC2
#error "cannot bodge and debug"
#endif
#ifdef AC_SIGNAL_DEBUG_WAITPIN_ON_PA5
#error "cannot bodge and debug"
#endif
#endif

#define SHORT_DISABLE PIN_PC3

#define ADC_INP PIN_PA1
#define ADC_INN PIN_PA2
#define ADC_DC PIN_PA3

// what type of display?
#define OLED_128x32
//#define OLED_96x16

#pragma endregion

#pragma region Global settings
// ************************************************************************************************
// ******* Global settings ********
// ************************************************************************************************

// MIN must be 0, as I cannot print negative values now.
// Volts
#define VOLT_MIN 0
#define VOLT_MAX 25

// MIN must be 0, as I cannot print negative values now.
// Ohms
#define ESR_MIN 0
#define ESR_MAX 20

// The overflow is determined by 2 factors:
// * ADC Overflow, normally only when the input/test signal clips. The reference signal should never clip.
// * a suitable full scale display value. This depends on the ratio between Ref and Test, but also the scale.
// Since the 4 scales are in decades, underflow is simply the overflow limit / 10
// In other words:
// Reference signal should never clip, but should be fairly high to allow for more resolution
// Input/test signal clip should only happen above the full scale display value.

// 12 bit ADC, but count on 11 bits. That is 2048. So about 3.5 digits
// Below, the highest range full scale value is to be given. Make it a nice round (integer) number.
// Adapt this to the amplification and the ADC reference voltage.
// Make sure you have some margin before:
//  * ADC clipping
//  * rail voltage clipping
#define ESR_FULLSCALE 100

// Some strings that appear at different spots.
const char strERROR[] = "ERROR";
const char strTimeOut[] = "timeout";
const char strOverrun[] = "overrun";
const char strLowV[] = "low v";
const char strOverrange[] = "overrange";
const char strShortProblem[] = "short problem";
const char strOverload[] = "overload";
const char strOver[] = "over";
const char strAUTO[] = "AUTO";
const char strON[] = "ON";
const char strOFF[] = "OFF";

#pragma endregion

#pragma region Settings
// ************************************************************************************************
// Settings
// ************************************************************************************************

#define SETTINGS_VERSION 2
struct Settings {
    // unint16_t: 0..65536
    uint8_t version;
    uint16_t iInternalVoltageMilliVoltAt1V;  // millivolts for 1 V theoretical ADC input
    uint16_t iInputVoltageMilliVoltAt1V;     // millivolts for 1 V theoretical ADC input
    int16_t  iInputVoltageOffset;            // ADC volts input offset
    uint16_t iRange0_1mOhms;                 // reference resistor 100uA range, times 1mOhm
    uint16_t iRange1_100uOhms;               // reference resistor 1mA range, times 100uOhm
    uint16_t iRange2_10uOhms;                // reference resistor 10mA range, times 10uOhm
    uint16_t iRange3_1uOhms;                 // reference resistor 100mA range, times 1uOhm

    uint16_t iT1_usecs;                      // DCIS T1, usecs
#define DCIS_T1_usecs_MIN 100
#define DCIS_T1_usecs_MAX 500
#define DCIS_T1_usecs_DEFAULT 250
    uint32_t iT2_usecs;                      // DCIS T2, usecs
#define DCIS_T2_usecs_MIN 100
#define DCIS_T2_usecs_MAX 50000L
#define DCIS_T2_usecs_DEFAULT 10000
    uint16_t iTPause_usecs;                  // DCIS T1-T2 pause, usecs
#define DCIS_TP_usecs_MIN 5000
#define DCIS_TP_usecs_MAX 10000
#define DCIS_TP_usecs_DEFAULT 5000

    uint8_t  iPLF_50Hz;                      // True if power line Frequency = 50Hz

    uint16_t ispare;

    uint16_t iInternalVoltageMilliVoltMin;   // min level in mV for the battery symbol
    uint16_t iInternalVoltageMilliVoltMax;   // max level in mV for the battery symbol
    uint16_t check;                          // CRC16 or some other checksum. 
}
  mySettings;


uint16_t settingsCalcCheck(void) {
    #define SETTINGS_CHECK 0x5A5A

    // TODO calculate CRC16
    return SETTINGS_CHECK;
}

/**
 * @brief Write the settings to EEPROM.
 * To be called after changing the settings.
 */
void writeSettings(void) {
    mySettings.check = settingsCalcCheck();
    EEPROM.put(0, mySettings);
}

// Forward decl
void dcisValidateSettings(void);

/**
 * @brief Read the settings from EEPROM.
 * To be called once at startup.
 */
void readSettings(void) {
    EEPROM.get(0, mySettings);

    if ((mySettings.version != SETTINGS_VERSION) || (mySettings.check != settingsCalcCheck())) {
        // init settings
        mySettings.version = SETTINGS_VERSION;
        
        // 1.00
        // 10.03
        mySettings.iInternalVoltageMilliVoltAt1V = 1000;
        mySettings.iInputVoltageMilliVoltAt1V = 10047;
        mySettings.iInputVoltageOffset = 60;

        // 45	47,018
        // 5	4,9771
        // 0,5	0,4703
        // 0,05	0,050
        mySettings.iRange0_1mOhms = 47018;
        mySettings.iRange1_100uOhms = 49771;
        mySettings.iRange2_10uOhms = 47030;
        mySettings.iRange3_1uOhms = 50000;

        // DCIS timings, usecs
        mySettings.iT1_usecs = DCIS_T1_usecs_DEFAULT;
        mySettings.iT2_usecs = DCIS_T2_usecs_DEFAULT;
        mySettings.iTPause_usecs = DCIS_TP_usecs_DEFAULT;

        mySettings.iPLF_50Hz = 1;
        dcisValidateSettings();

        // Alkaline: 1100 - 1500
        // NiMH: 0900-1300
        // but do not go below 800, as the MCP1642 does not go below that
        mySettings.iInternalVoltageMilliVoltMin = 900;
        mySettings.iInternalVoltageMilliVoltMax = 1500;

        writeSettings();
    }
}

/**
 * @brief Translate a voltage to a battery percentage, based on the used battery type
 *
 * @param v Internal battery voltage
 * @return int the percentage
 */
int settingsTranslateBattVoltageToPercentage(double v) {
    int battLowmV = mySettings.iInternalVoltageMilliVoltMin;
    int battHighmV = mySettings.iInternalVoltageMilliVoltMax;

    // no rounding needed, this is imprecise enough
    int mv = v * 1000.0;
    if (mv < battLowmV)
        mv = battLowmV;
    if (mv > battHighmV)
        mv = battHighmV;

    // Consider it linear. Good enough.
    return map(mv, battLowmV, battHighmV, 0, 100);
}

bool settingsShow4Digits(void) {
    // TODO: get requested precision for impedance from settings. 3 or 4 digits
    return true;
}

#pragma endregion

#pragma region IO Control
// ************************************************************************************************
// IO Control
// ************************************************************************************************

// CPU_PWR_ON : 1 = ON, 0 = OFF
inline void setPowerOn(void) { digitalWrite(CPU_PWR_ON, HIGH); }
inline void setPowerOff(void) { digitalWrite(CPU_PWR_ON, LOW); }

// OUT_SW : 1 = SIGNAL_OUT = DCIS, 0 = SIGNAL = AC
inline void setTestModeDCIS(void) { digitalWrite(OUT_SW, HIGH); }
inline void setTestModeAC(void) { digitalWrite(OUT_SW, LOW); }

// Forward decl
void setup_ADC(bool);

// ADC_IN_SW : 1 = REF to ADC_INx, 0 = SENSE to ADC_INx, 1 = BATT to ADC_DC, 0 = TEST to ADC_DC
enum ADCin : uint8_t { adcin_input = 0,
                       adcin_ref = 1,
                       adcin_batt = 1 };
/**
 * @brief Set the ADC input mux.
 * To be used for diff input (AC and DCIS) and single input (DC) measurements.
 * @param input the ADC input to be used. See enum ADCin
 */
inline void setADCInMode(uint8_t input) { digitalWrite(ADC_IN_SW, input); }
// (Arduino IDE does not allow enums as function parameters....)

// SHORT_SW : 0 = REF, 1 = SENSE
// SHORT_DISABLE : 0 = short, 1 = no short

/**
 * @brief Read the scale to be applied on single ended readings (DC)
 *
 * @param input The item to measure. See enum ADCin
 * @param pOffset the offset to be applied to the raw value.
 * @return double the scale factor
 */
double settingsGetDCScale(uint8_t input, int *pOffset) {
    // get the scales from EEPROM
    if (input == adcin_input) {
        if (pOffset)
            *pOffset = mySettings.iInputVoltageOffset;
        return mySettings.iInputVoltageMilliVoltAt1V / 1000.0;
    } else {
        if (pOffset)
            *pOffset = 0;
        return mySettings.iInternalVoltageMilliVoltAt1V / 1000.0;
    }
}

/**
 * @brief Force a short on the Ref input
 */
inline void setShortOnRef(void) {
    digitalWrite(SHORT_SW, LOW);
    digitalWrite(SHORT_DISABLE, LOW);
}

/**
 * @brief Force a short on the Sense input
 */
inline void setShortOnInput(void) {
    digitalWrite(SHORT_SW, HIGH);
    digitalWrite(SHORT_DISABLE, LOW);
}

inline void setShortOff(void) {
    digitalWrite(SHORT_DISABLE, HIGH);
}

struct adcShortResults {
    int duration;
    int32_t rawp;
    int32_t rawn;
};

#define SHORT_MAX_DURATION_MS 1000
#define SHORT_MIN_DURATION_MS 25

// for shorting, I measure 2 signals: INP and INN
// I accept signals that are maximum SHORT_MAX_DIFFERENCE apart, 
// and where the average of the 2 is in the band (GNDA_ON_12BIT +/- SHORT_MAX_OFFSET)
// Signals should be around VCC/2, on a 2.048V 12 bit scale, so (3.3 / 2) * (4096/2.048) = 3300
#define SHORT_MAX_DIFFERENCE 200
#define SHORT_MAX_OFFSET 300
#define GNDA_ON_12BIT 3300

#define SHORT_ULIMIT GNDA_ON_12BIT + SHORT_MAX_OFFSET + SHORT_MAX_DIFFERENCE
#define SHORT_LLIMIT GNDA_ON_12BIT - SHORT_MAX_OFFSET - SHORT_MAX_DIFFERENCE

/**
 * @brief Force a short on a specified input, up to a max duration
 *
 * @param bInput true for the Test input
 * @param bLoad true for load at 50%
 * @param pResults see struct adcShortResults
 * @return approximation of the duration. -1 if short was impossible in the maximum time
 */
int setShortWithDuration(bool bInput, bool bLoad, struct adcShortResults *pResults) {
    int32_t rawp = 0;
    int32_t rawn = 0;
    int counterOK = 0;

    if (pResults) {
        pResults->duration = 0;
        pResults->rawp = 0;
        pResults->rawn = 0;
    }

    // setup
    if (bInput)
        setShortOnInput();
    else
        setShortOnRef();
    digitalWriteFast(SIGNAL_OUT, LOW);
    if (bLoad)
        setTestModeAC();  // force 50% current
    else
        setTestModeDCIS();  // force 0% current
    setup_ADC(true);
    if (bInput)
        setADCInMode(adcin_input);
    else
        setADCInMode(adcin_ref);

    // throw first measurement away
    rawp = analogReadEnh(ADC_INP, ADC_NATIVE_RESOLUTION, 0);  // is about 20us

    for (int i = 0; i < SHORT_MAX_DURATION_MS; i++) {
        rawp = analogReadEnh(ADC_INP, ADC_NATIVE_RESOLUTION, 0);
        rawn = analogReadEnh(ADC_INN, ADC_NATIVE_RESOLUTION, 0);
        if ((rawp > SHORT_ULIMIT) || (rawp < SHORT_LLIMIT) ||
            (rawn > SHORT_ULIMIT) || (rawn < SHORT_LLIMIT) || 
            (abs(rawn-rawp) > SHORT_MAX_DIFFERENCE))
            counterOK = 0;
        else
            counterOK++;
        if (counterOK > SHORT_MIN_DURATION_MS) {
            setShortOff();
            // Serial.printf(" P: %lu, N: %lu",rawp,rawn);
            if (pResults) {
                pResults->duration = i;
                pResults->rawp = rawp;
                pResults->rawn = rawn;
            }
            return i;
        }
        delayMicroseconds(960);
    }

    setShortOff();
    if (pResults) {
        pResults->duration = -1;
        pResults->rawp = rawp;
        pResults->rawn = rawn;
    }
    return -1;
}

/**
 * @brief Forces a short on the input while in rest, but no current draw.
 * The reverse is setShortOff();
 */
void setShortInRest(void) {
    setShortOnInput();
    digitalWriteFast(SIGNAL_OUT, LOW);
    setTestModeDCIS();  // force 0 current
}

// Current ranges:
enum IRange : uint8_t { range_min = 0,
                        range_100uA = 0,
                        range_1mA = 1,
                        range_10mA = 2,
                        range_100mA = 3,
                        range_max = range_100mA };
//        SW_A  SW_B EN_1mA EN_10mA EN_100mA
// 100uA  0     0    0      0       0
//   1mA  1     0    1      0       0
//  10mA  0     1    x      1       0
// 100mA  1     1    x      x       1

/**
 * @brief The last set current range.
 * To be used only by getIRange and setIRange
 *
 */
static uint8_t _iCurrentRange = 0;

/**
 * @brief Read the scale to be applied on ratiometric (AC or DCIS) readings.
 * Offset is 0, due to the style of measurement.
 *
 * @param range the selected range. Get that from getIRange()
 * @return double: the scale factor for the runAC.. and runDCIS.. functions.
 */
double settingsGetRatio(uint8_t range) {
    // get the scales from EEPROM

    double scale = 0.0;
    // use the range to scale
    switch (range) {
        case range_100uA:
            scale = mySettings.iRange0_1mOhms / 1000.0;
            break;
        case range_1mA:
            scale = mySettings.iRange1_100uOhms / 10000.0;
            break;
        case range_10mA:
            scale = mySettings.iRange2_10uOhms / 100000.0;
            break;
        case range_100mA:
            scale = mySettings.iRange3_1uOhms / 1000000.0;
            break;
        default:
            scale = 1.0;
    }
    return scale;
}

/**
 * @brief Get the current range set, from local var to make it faster
 *
 * @return enum IRange
 */
inline uint8_t getIRange(void) { return _iCurrentRange; }

/**
 * @brief Set the current range
 *
 * @param range enum IRange
 */
inline void setIRange(uint8_t range) {
    digitalWrite(REF_SW_A, range & 1);
    digitalWrite(REF_SW_B, range & 2);
    _iCurrentRange = range;
#ifdef BODGE_REF_SW
    //         PA5   PC2
    //  100uA    1     1
    //    1mA    0     1
    //   10mA    1     0
    //  100mA    0     0
    digitalWrite(PIN_PA5, !(range & 1));
    digitalWrite(PIN_PC2, !(range & 2));
#endif
}

/**
 * @brief return the Current range as a string
 *
 * @param range enum IRange (Arduino IDE does not allow enums as function parameters....)
 * @return fixed string (4 chars wide)
 */
const char *szgetIRange(uint8_t range) {
    switch (range) {
        case range_100uA:
            return "100uA";
        case range_1mA:
            return "  1mA";
        case range_10mA:
            return " 10mA";
        case range_100mA:
            return "100mA";
        default:
            return "???mA";
    }
}

/**
 * @brief return the presently set current range as a string
 *
 * @return fixed string
 */
const char *szgetIRange(void) {
    return szgetIRange(getIRange());
}

/**
 * @brief Get the resistance upper limit value for overflow detection
 *
 * @param range enum IRange (Arduino IDE does not allow enums as function parameters....)
 * @return float
 */
float getRUpperLimit(uint8_t range) {
    switch (range) {
        case range_100uA:
            return 1000.0; // upper limit is absent really, this is the display limit
        case range_1mA:
            return ESR_FULLSCALE / 10.0;
        case range_10mA:
            return ESR_FULLSCALE / 100.0;
        case range_100mA:
            return ESR_FULLSCALE / 1000.0;
        default:
            return (float)ESR_FULLSCALE;
    }
}

/**
 * @brief Get the resistance under limit value for underflow detection.
 * Roughly upperlimit / 10, with a small hysteresis added
 *
 * @param range enum IRange (Arduino IDE does not allow enums as function parameters....)
 * @return float
 */
float getRUnderLimit(uint8_t range) {
    switch (range) {
        case range_100uA:
            return ESR_FULLSCALE / 10.1; 
        case range_1mA:
            return ESR_FULLSCALE / 110.0;
        case range_10mA:
            return ESR_FULLSCALE / 1100.0;
        case range_100mA:
            return 0.0; // this is the display limit
        default:
            return (float)ESR_FULLSCALE;
    }
}
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
void loop() {
    loop_UI();
    delayMicroseconds(10000);}
#endif

#pragma endregion

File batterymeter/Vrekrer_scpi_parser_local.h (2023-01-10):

/*! 
@file Vrekrer_scpi_parser.h 
Header file.
*/

// This is the Vrekrer_scpi_parser library collapsed into 1 header file, with my adaptations:
// extra parameter in ProcessInput and GetMessage: ignore_char
// removed the timeout in GetMessage
// more stuff in PrintDebugInfo

#ifndef VREKRER_SCPI_PARSER_H_
#define VREKRER_SCPI_PARSER_H_

/// Max branch size of the command tree and max number of parameters.
#ifndef SCPI_ARRAY_SYZE
  #define SCPI_ARRAY_SYZE 6
#endif

/// Max number of valid tokens.
#ifndef SCPI_MAX_TOKENS
  #define SCPI_MAX_TOKENS 15
#endif

/// Max number of registered commands.
#ifndef SCPI_MAX_COMMANDS
  #define SCPI_MAX_COMMANDS 20
#endif

/// Length of the message buffer.
#ifndef SCPI_BUFFER_LENGTH
  #define SCPI_BUFFER_LENGTH 64
#endif

/// Timeout, in miliseconds, for GetMessage and ProcessInput.
#ifndef SCPI_TIMEOUT
  #define SCPI_TIMEOUT 10
#endif

/// Integer size used for hashes.
#ifndef SCPI_HASH_TYPE
  #define SCPI_HASH_TYPE uint8_t
#endif

#include "Arduino.h"

/*!
 Variable size string array class.

 The array must be filled using the \c Append method (acts as a LIFO stack Push). \n
 Values can be extracted (and removed) using the \c Pop function (LIFO stack Pop). \n
 Both \c Append and \c Pop modifies the \c Size of the array. \n
 Values can be read (without removing them) using the following methods: \n
  \li \c First() : Returns the first value appended to the array.
  \li \c Last()  : Returns the last value appended to the array.
  \li Indexing (e.g. \c my_array[1] to get the second value of the array).

 The max size of the array is defined by \c SCPI_ARRAY_SYZE (default 6).
*/
class SCPI_String_Array {
 public:
  char* operator[](const byte index);  //Add indexing capability
  void Append(char* value);            //Append new string (LIFO stack Push)
  char* Pop();                         //LIFO stack Pop
  char* First();                       //Returns the first element of the array
  char* Last();                        //Returns the last element of the array
  uint8_t Size();                      //Array size
 protected:
  const uint8_t storage_size = SCPI_ARRAY_SYZE; //Max size of the array 
  uint8_t size_ = 0;              //Internal array size
  char* values_[SCPI_ARRAY_SYZE]; //Storage of the strings
};

/*!
 String array class used to store the tokens of a command.
 @see SCPI_String_Array
*/
class SCPI_Commands : public SCPI_String_Array {
 public:
  //Dummy constructor.
  SCPI_Commands();
  //Constructor that extracts and tokenize a command from a message
  SCPI_Commands(char* message);
  ///Not processed part of the message after the constructor is called.
  char* not_processed_message;
};

/*!
 String array class used to store the parameters found after a command.
 @see SCPI_String_Array
*/
class SCPI_Parameters : public SCPI_String_Array {
 public:
  //Dummy constructor.
  SCPI_Parameters();
  //Constructor that extracts and splits parameters from a message
  SCPI_Parameters(char *message);
  ///Not processed part of the message after the constructor is called.
  char* not_processed_message;
};

///Alias of SCPI_Commands.
typedef SCPI_Commands SCPI_C;

///Alias of SCPI_Parameters.
typedef SCPI_Parameters SCPI_P;

///Void template used with SCPI_Parser::RegisterCommand.
typedef void (*SCPI_caller_t)(SCPI_Commands, SCPI_Parameters, Stream&);

/// Integer size used for hashes.
typedef SCPI_HASH_TYPE scpi_hash_t;

/*!
  Main class of the HB_SCPI_Parser library.
*/
class SCPI_Parser {
 public:
  //Constructor
  SCPI_Parser();
  //Change the TreeBase for the next RegisterCommand calls
  void SetCommandTreeBase(char* tree_base);
  //SetCommandTreeBase version with RAM string support
  void SetCommandTreeBase(const char* tree_base);
  //SetCommandTreeBase version with Flash strings (F() macro) support
  void SetCommandTreeBase(const __FlashStringHelper* tree_base);
  //Registers a new valid command and associate a procedure to it
  void RegisterCommand(char* command, SCPI_caller_t caller);
  //RegisterCommand version with RAM string support.
  void RegisterCommand(const char* command, SCPI_caller_t caller);
  //RegisterCommand version with Flash strings (F() macro) support
  void RegisterCommand(const __FlashStringHelper* command, SCPI_caller_t caller);
  //Set the function to be used by the error handler.
  void SetErrorHandler(SCPI_caller_t caller);
  ///SCPI Error codes.
  enum class ErrorCode{
    ///No error
    NoError,
    ///Unknown command received.
    UnknownCommand,
    ///Timeout before receiving the termination chars.
    Timeout,
    ///Message buffer overflow.
    BufferOverflow,
  };
  ///Variable that holds the last error code.
  ErrorCode last_error = ErrorCode::NoError;
  //Process a message and execute it a valid command is found
  void Execute(char* message, Stream& interface);
  //Gets a message from a Stream interface and execute it
  void ProcessInput(Stream &interface, const char* term_chars, char ignore_char);
  //Gets a message from a Stream interface
  char* GetMessage(Stream& interface, const char* term_chars, char ignore_char);
  //Prints registered tokens and command hashes to the serial interface
  void PrintDebugInfo();
  ///Magic number used for hashing the commands
  scpi_hash_t hash_magic_number = 37;
  
 protected:
  //Length of the message buffer.
  const uint8_t buffer_length = SCPI_BUFFER_LENGTH;
  //Timeout, in miliseconds, for GetMessage and ProcessInput.
  const int timeout = SCPI_TIMEOUT;
  //Max number of valid tokens.
  const uint8_t max_tokens = SCPI_MAX_TOKENS;
  //Max number of registered commands.
  const uint8_t max_commands = SCPI_MAX_COMMANDS;

  //Add a token to the tokens' storage
  void AddToken_(char* token);
  //Get a hash from a command
  scpi_hash_t GetCommandCode_(SCPI_Commands& commands);
  //Number of stored tokens
  uint8_t tokens_size_ = 0;
  //Storage for tokens
  char *tokens_[SCPI_MAX_TOKENS];
  //Number of registered commands
  uint8_t codes_size_ = 0;
  //Registered commands' hash storage
  scpi_hash_t valid_codes_[SCPI_MAX_COMMANDS];
  //Pointers to the functions to be called when a valid command is received
  SCPI_caller_t callers_[SCPI_MAX_COMMANDS+1];
  //Branch's hash used when calculating unique codes (0 for root)
  scpi_hash_t tree_code_ = 0;
  //Message buffer.
  char msg_buffer_[SCPI_BUFFER_LENGTH];
  //Length of the readed message
  uint8_t message_length_ = 0;
  //Varible used for checking timeout errors
  unsigned long time_checker_;
};
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

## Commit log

2023-01-10 First published version
    [08_047456d.brd, 1593D.igs, 1593D.stp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]
2023-01-17 better doc
    [batterymeter.kicad_sch]
2023-02-16 better input voltage readings
    [DCInputCalibration.xlsx]

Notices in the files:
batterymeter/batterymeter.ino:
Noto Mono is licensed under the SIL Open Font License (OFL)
